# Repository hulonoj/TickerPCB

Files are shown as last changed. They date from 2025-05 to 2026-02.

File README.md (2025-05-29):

# ESP32 14-Segment Ticker Board

A custom-built ESP32-based project using 14-segment hex displays to show real-time data like a clock, stock prices, temperature, and a chess timer.
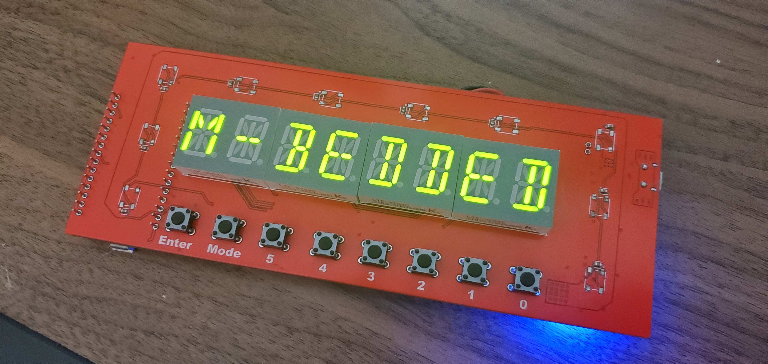
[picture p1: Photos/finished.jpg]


## What It Does
- Pulls real-time data via Wi-Fi
- Displays info on 8 14-segment displays
- Controlled with 7 physical buttons
- Runs on battery with power management

## Current Modes
- Temperature from 2 i2c sensors
- Real time clock accurate to ~1 second
- Stock Price for any ticker symbol you input
- Chess clock with 5 differet base times and increment

## Photos
Finished Board!

Shows live temperature readings in [temperature testing video](Photos/TempTesting.mp4) and accurate clock in [clock testing video](Photos/ClockTesting.mp4)

Temperature Readings
Clock Time

Schematic and Layout

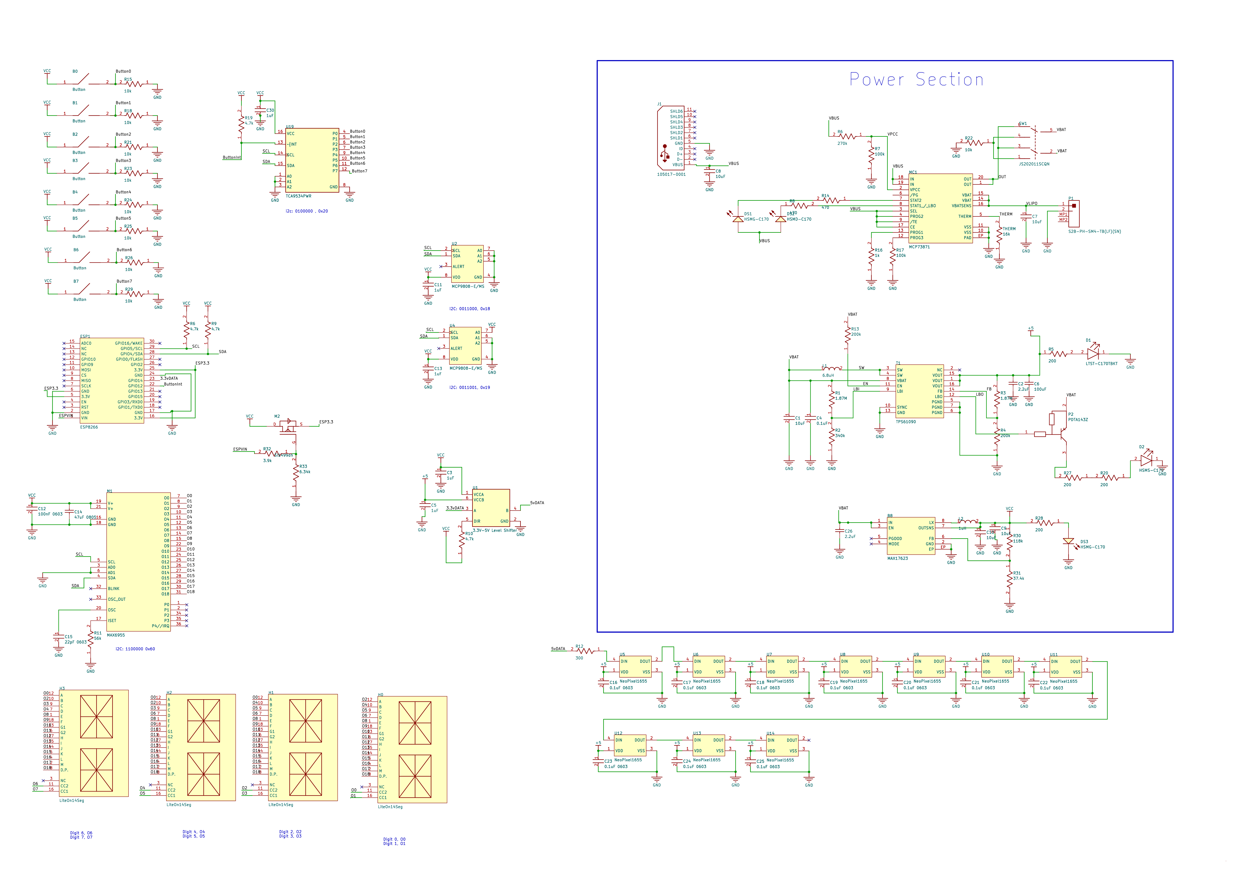
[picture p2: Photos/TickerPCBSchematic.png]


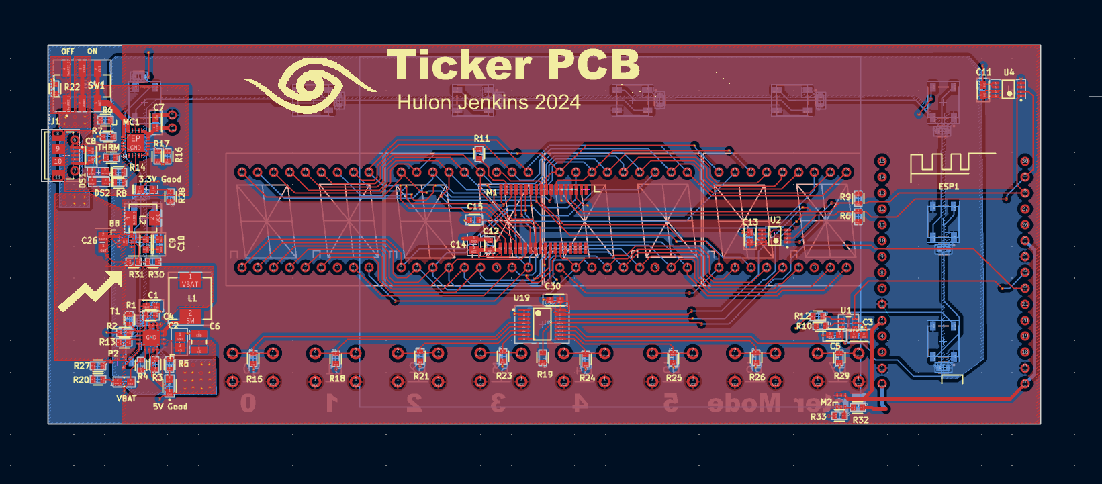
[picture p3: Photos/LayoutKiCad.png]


## Code Overview
Firmware is written in C++ and manages:
- I2C communication with display drivers
- GPIO input from buttons
- Wi-Fi data fetching
- State switching between display modes

Buttons presses trigger interrupts which are then handled and change state machines to change or move within modes.

## 📚 Notes
I designed and built this project as a personal challenge to deepen my embedded systems skills. The board and code were developed from scratch, and photos illustrate the final product.

## 📝 License
MIT

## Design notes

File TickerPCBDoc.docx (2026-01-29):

Design Considerations

Current from battery and to 3.3 and 5V rails (but didn’t calculate if BMS could handle 3.7V current which would be boosted to 5V).

Made the board 2 layers for cost reasons, even though 4 layers would be significantly better.

Issues

1. When soldering on the NeoPixel LEDS and powering up the board, the entire board shut down. This happened every time the LEDs were soldered on. I removed the LEDs and the resistor in series with the data line. My hypothesis is that the LEDs drew too much current (not for the 3.7v to 5V boost converter) but from the BMS since more current would be flowing at 3.7v compared to 5V. I didn’t get the LEDs to work on this design. From the datasheet “The ideal diode between VBAT and OUT is designed to drive a maximum current up to 2A. The built-in thermal shutdown protection may turn the MCP73871 device off with high current”

I designed a PCB using an MCP73871 to manage a 3.7 V Li-ion battery and power my system. The MCP73871’s SYS output feeds a boost converter that steps the voltage up to 5 V for NeoPixel LEDs. On paper this looked fine because the chip’s current rating seemed high enough.

In practice, as soon as I solder even a single NeoPixel onto the board and power it on, the entire system shuts down. What’s happening is that the NeoPixels and the boost converter create a large inrush current at startup. That transient load causes the MCP73871’s power-path circuitry on the SYS pin to brown out or current-limit, so it disconnects the output and everything turns off. The issue isn’t average current, it’s the startup surge and the fact that SYS is not meant to supply large, fast, pulsed loads through a boost converter.

The fix is to power the boost converter directly from the battery instead of the SYS pin and to add adequate bulk capacitance. That way the battery handles the current spikes, the MCP73871 only manages charging and light system loads, and the system no longer collapses when the LEDs are connected.

2. When placing the battery onto the board, I noticed that the battery positive and negative terminals were inverted compared to what the online version said. The battery connector mounts in a certain way based on the polarity and can only be plugged in one way. Since the battery terminals were reversed, I cut and stripped the wires, and resoldered them on and plugged the battery in so it worked. I also ordered a new higher capacity battery which definitely had the right connector order for a more permanent solution.

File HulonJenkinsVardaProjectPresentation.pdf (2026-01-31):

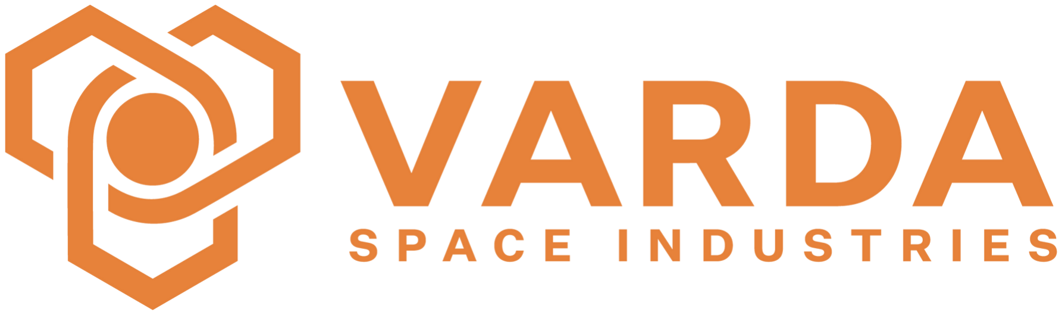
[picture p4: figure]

# Project Presentation

Hulon Jenkins

## Agenda

- About Me
- University/Microsoft Projects
- Personal Project Overview
- Planning
- Architecture
- Parts Selection
- Schematic & Layout
- Roadblocks and Debugging
- Software/Firmware Quick Look
- Results and Lessons Learned
- How I Engineer
- Questions
- Demo (if time)

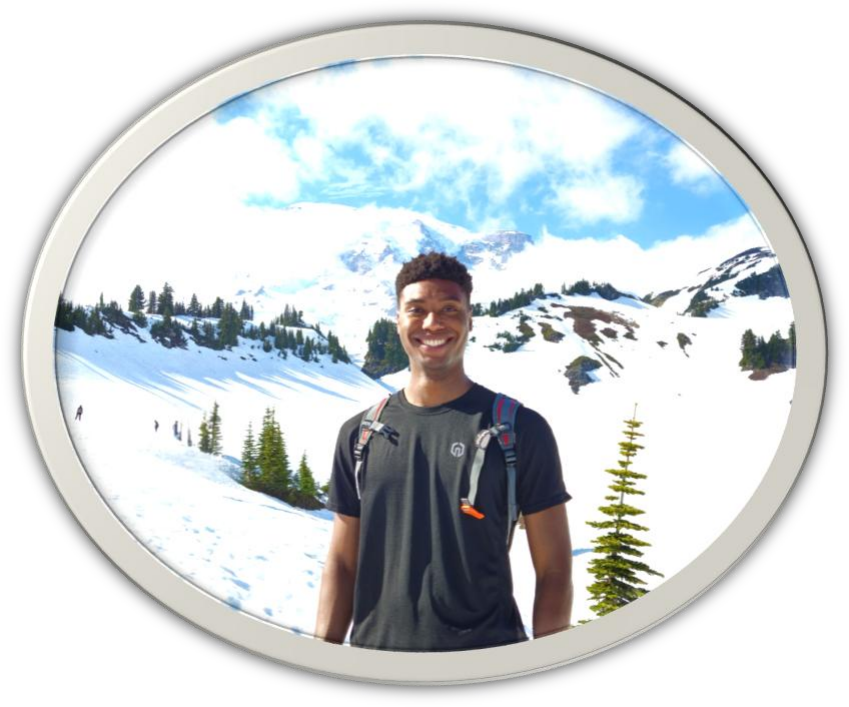
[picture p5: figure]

## About Me – Hulon Jenkins

Focus
- Embedded hardware and electronics design and bring up Education
- BSE Computer Engineering from University of Michigan
- Currently pursuing MS Electrical Engineering part time through University of Colorado Boulder
Experience
- Embedded Hardware Team Lead and member on Michigan Mars Rover Team
- Currently work at Microsoft (C++ Compiler)
Interests
- Spaceflight, Table Tennis, 3d Printing

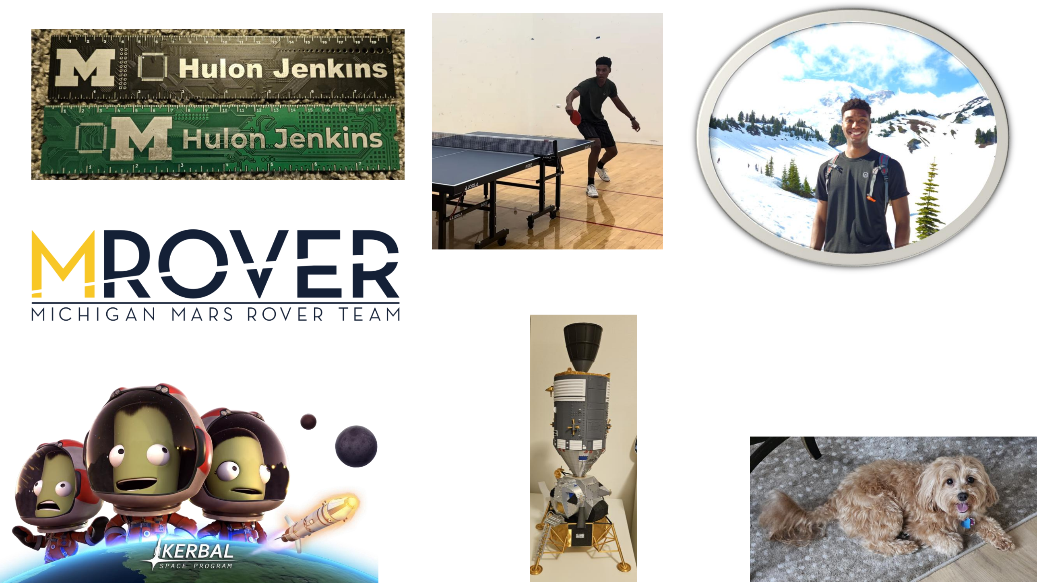
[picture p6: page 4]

## University - MROVER

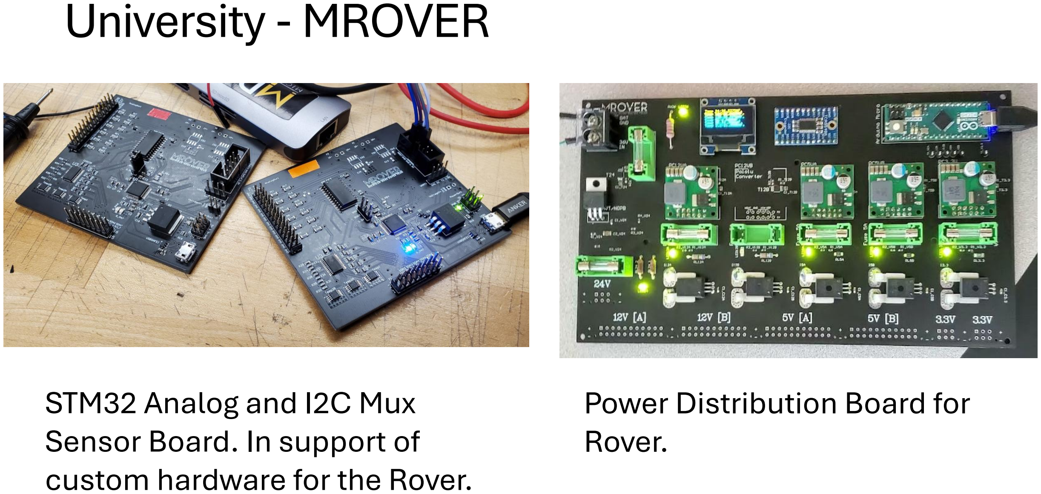
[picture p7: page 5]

Power Distribution Board for Rover.

STM32 Analog and I2C Mux
Sensor Board. In support of custom hardware for the Rover.

## University - Classes

- A Drop-In Wire Replacement using Fiber Optics
- Is Protocol Agnostic
- Replicates signals on wires. Which can be interpreted as I2C, SPI, UART, GPIO, etc.

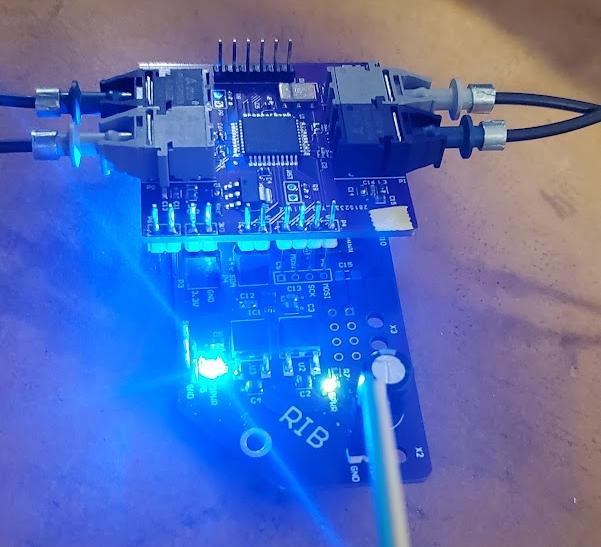
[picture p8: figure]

- We used it to replicate I2C over a length of 5 meters

## Microsoft

- Pattern Matching Software Security Tool Team
- Implemented patterns and logic to statically match a secret and validate if that secret was still live
- C++ Compiler Team
- Worked on a large optimization with tail calling which is used in upcoming Python Interpreter!

## Personal Project Overview

- ESP8266 based 14-segment display board
- Battery powered
- 8 Button input
- Wifi Connected

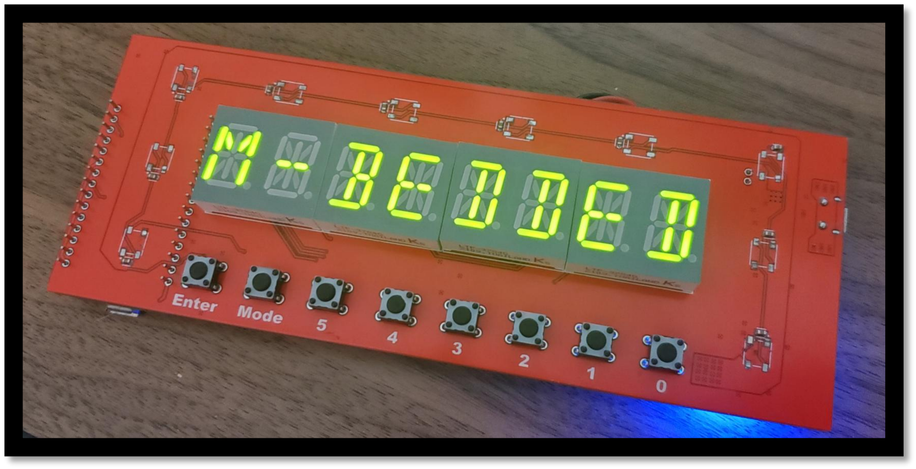
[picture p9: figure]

## Project Requirements & Initial Planning

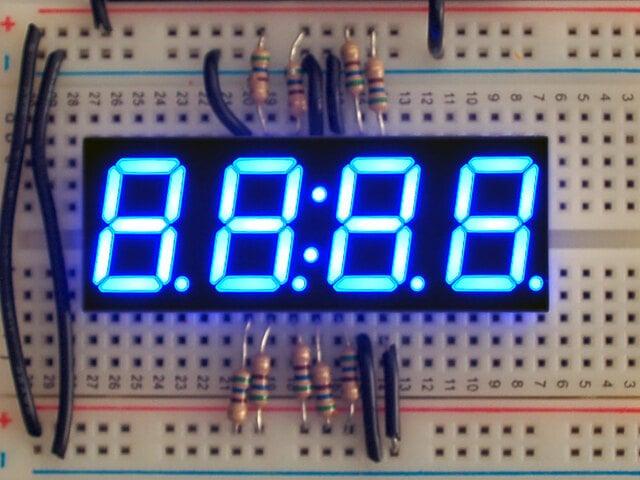
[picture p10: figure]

- Main goal, be able to display real time stock data on
hex displays
- Must be internet connected

## Project Requirements & Initial Planning

- 14-segment allows for alphanumeric characters.
- Can display temperature data as well
- Mobile, so battery powered
- All interfacing will be through the 14-segments displays
- Would need buttons for inputs
- Have LEDs that can change color/brightness as well
- Main goal, be able to display real time stock data on hex displays
- Must be internet connected

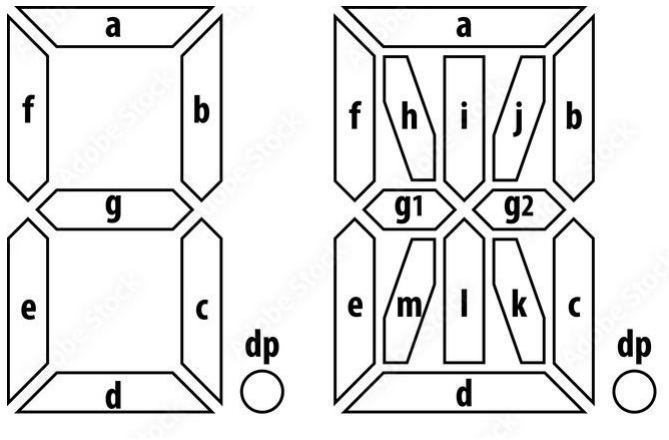
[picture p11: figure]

## Design and Architecture (1/2)

Connectivity and Main Controller
- 3.3V Esp8266 for Wi-Fi connectivity

Power
- 3.7V rechargeable LiPo battery

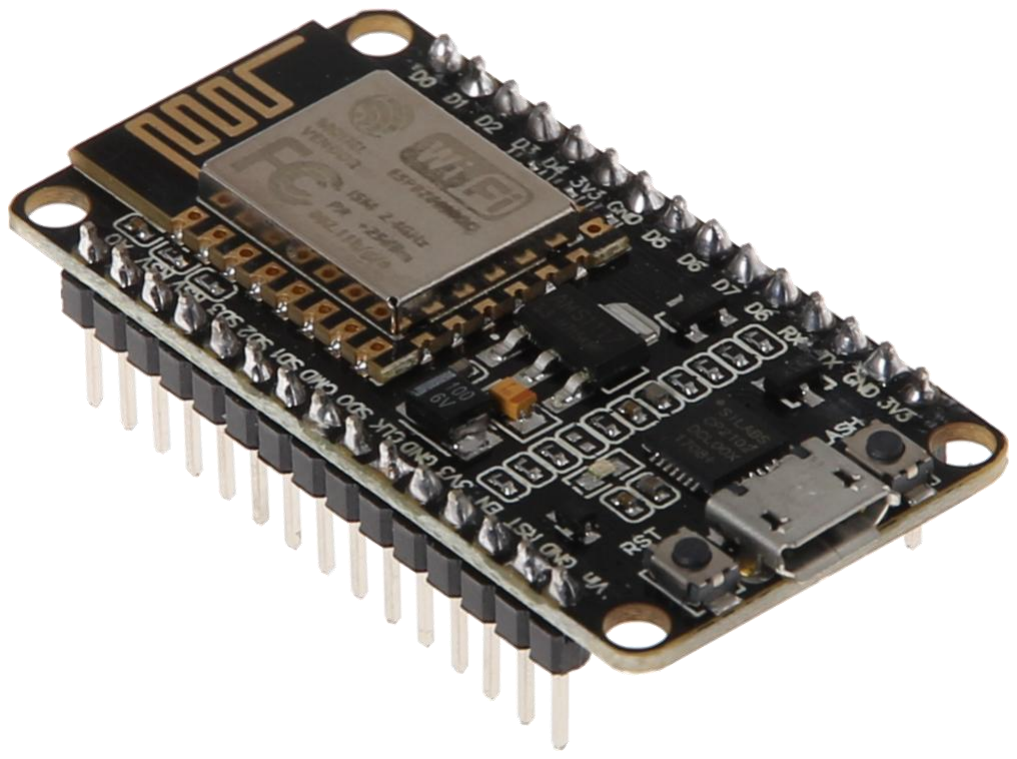
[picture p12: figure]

- Passthrough charging IC (Can charge battery and use simultaneously)
- Buck Converter for 3.7V → 3.3V
- Boost Converter for 3.7V → 5V

## Design and Architecture (2/2)

Outputs
- 3.3V 14-Segment Displays
- 5V individually addressable NeoPixel LEDs Inputs
- Multiple tactile switches
Logic
- Logic level shifter for 3.3V Esp8266 logic to 5V for NeoPixels
- 14-Segment Control IC for simplicity
- 3.3V Temperature sensors

## Block Diagram

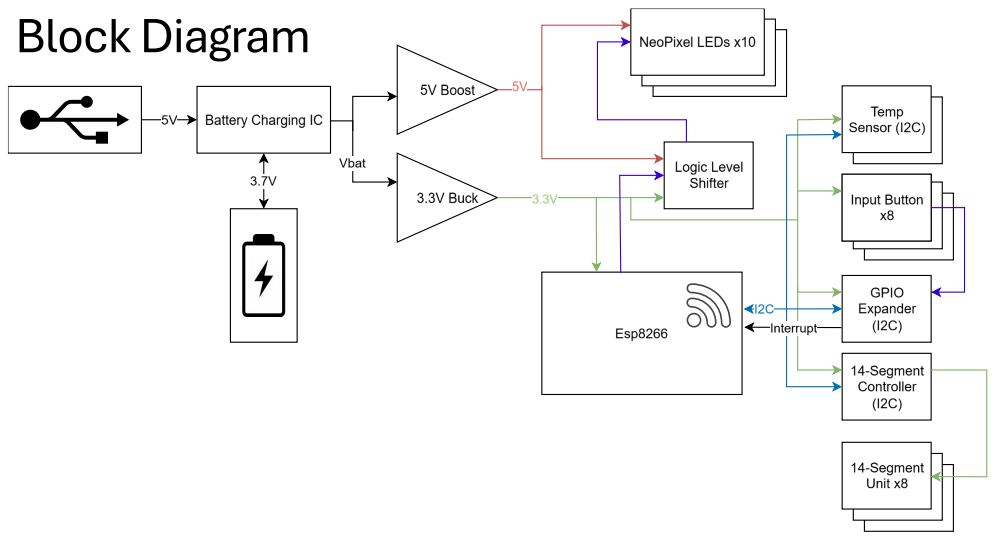
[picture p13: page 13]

## Implementation Details (1/2)

Functionality | IC Selected | Why
Battery Charger | MCP73871 | CC/CV, Load Sharing + Battery Charging, Indication and Safety (temp, short protection)
14-Segment Controller | MAX6955 | I2C, Can control 8 14-segments, can PWM LEDs to reduce current draw
Buck Converter | MAX17623 | Up to 1A @ 3.3V
Boost Converter | TPS61090 | Up to 500mA @ 5V
GPIO Expander | TCA9534PWR | I2C, 8 inputs, has interrupt pin
Logic Level Shifter | SN74LVC1T45-Q1 | Converters 3.3V logic to 5V with 3.9ns delay
Temperature Sensors | MCP9808-E/MS | I2C, address pins, 0.0625C accuracy
NeoPixels | NeoPixel 1655 | Multicolor, individually addressable

## Implementation Details (2/2)

Functionality | Details | Why
MCU | ESP8266 Dev Board | I had the dev board in hand already, was going to have enough external circuitry to test
USB | Micro USB connector | The Esp8266 already has a Micro USB. I’d prefer USB Type C, but would prefer consistency
Buttons | Tactile Switches | Cheap easy to use with pull-down resistor
Battery | 3000 mAh 3.7V Battery | Expected ~40mA*8 + ~30mA*10 + ~100mA = 720mA of current, so would last a ~4 hours on battery power at full brightness

## Block Diagram

## Initial Trials

- Breadboarded 14-segment displays and Esp8266 connectivity and control

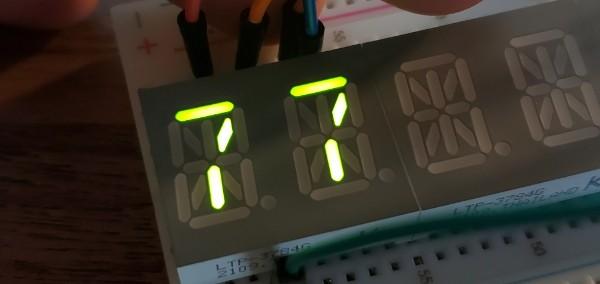
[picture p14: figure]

## Schematic

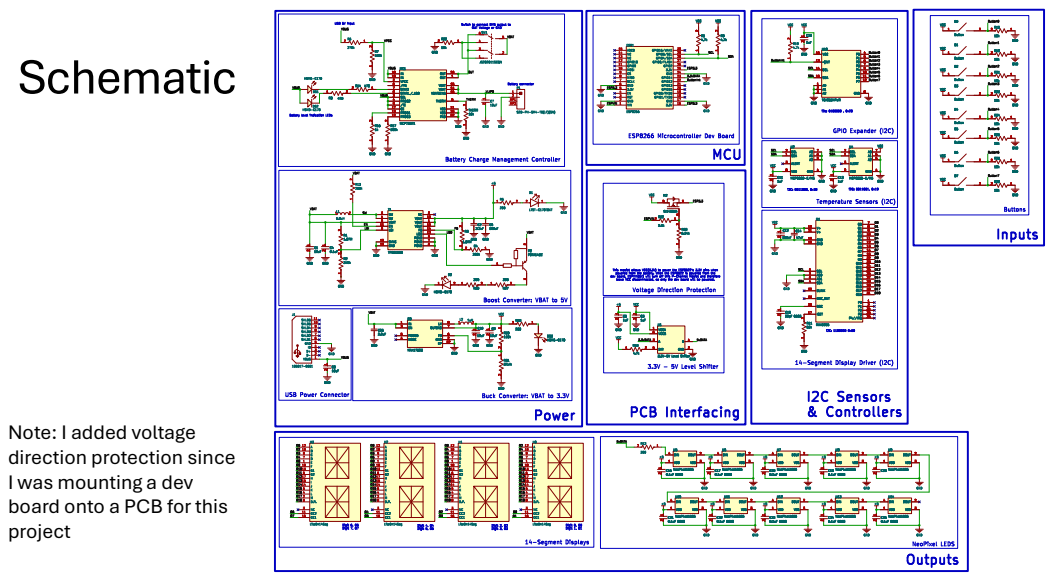
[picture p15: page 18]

Note: I added voltage
direction protection since
I was mounting a dev
board onto a PCB for this
project

## PCB layout (2 layer)

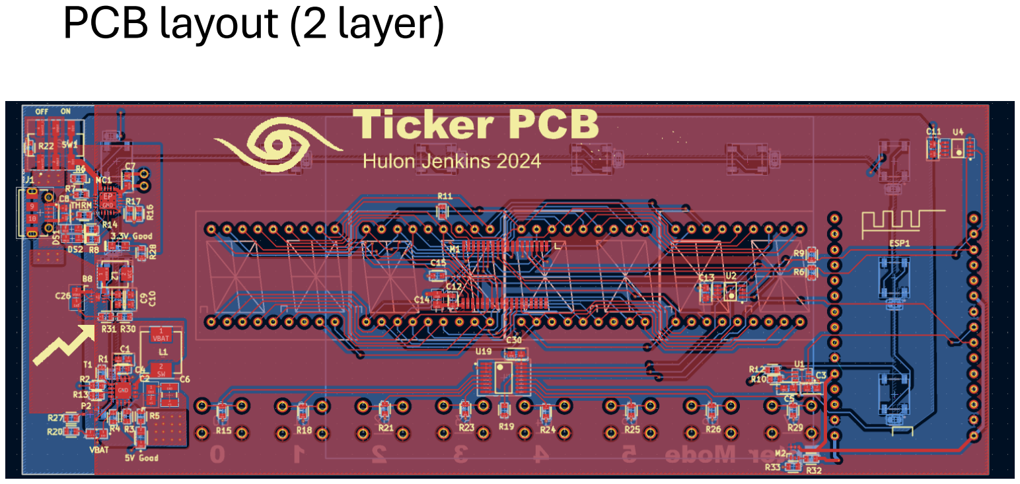
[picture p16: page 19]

## Integration and Build Process

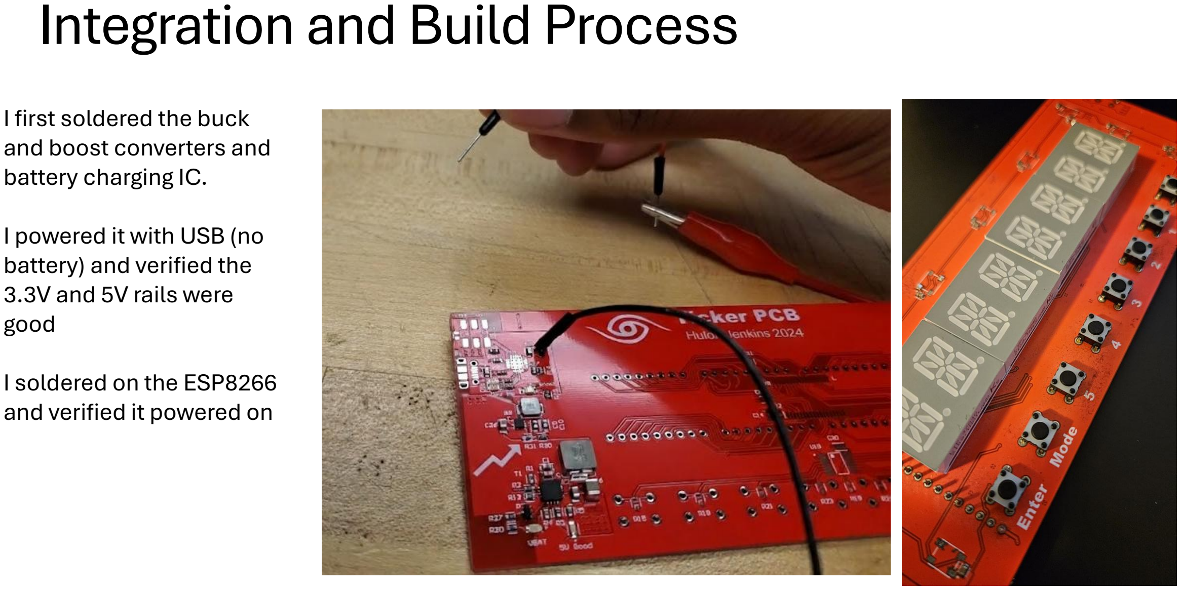
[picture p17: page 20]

I first soldered the buck
and boost converters and
battery charging IC.

I powered it with USB (no
battery) and verified the
3.3V and 5V rails were
good

I soldered on the ESP8266
and verified it powered on

## Roadblocks and Debugging

- When I soldered on NeoPixel LEDs, all power good LEDs went off and everything on board instantly shut down

## Investigation Steps

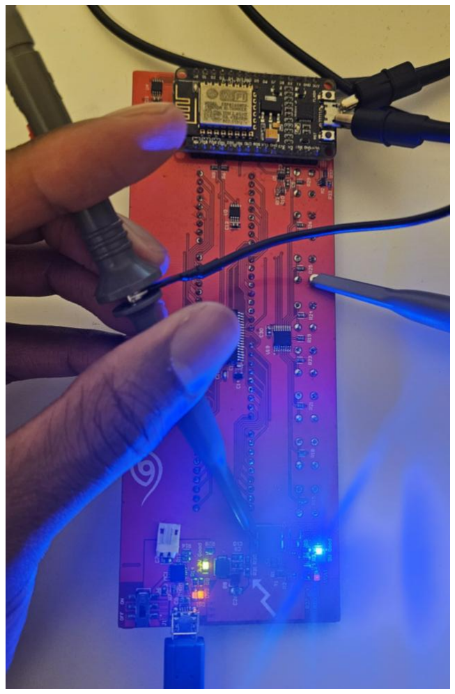
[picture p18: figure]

- Desoldered the NeoPixels and the board worked again.
- Verified footprint and pinout was correct.
- Verified once more 5V was good.
- Tried with other Neopixels but saw the same behavior.

## Investigation Steps

- I started attaching loads to the 5V rail and checking the voltage; it was fine.
- However, I noticed when I used a 47.5Ohm power resistor load, the 3.3V LED no longer lit up…
- Time to scope…

## Debugging

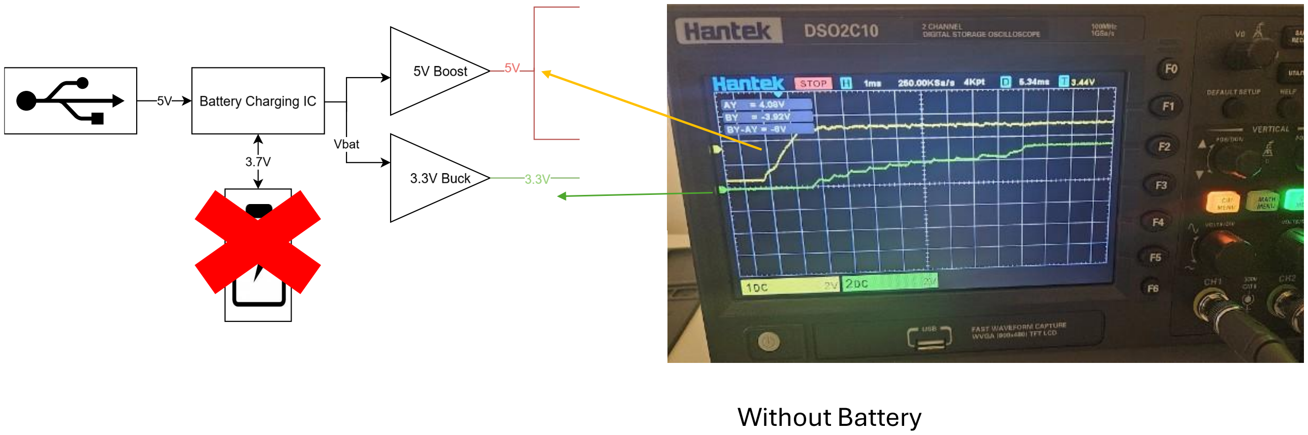
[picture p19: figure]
Without Battery

3.3V takes 9ms to ramp up!

## Debugging

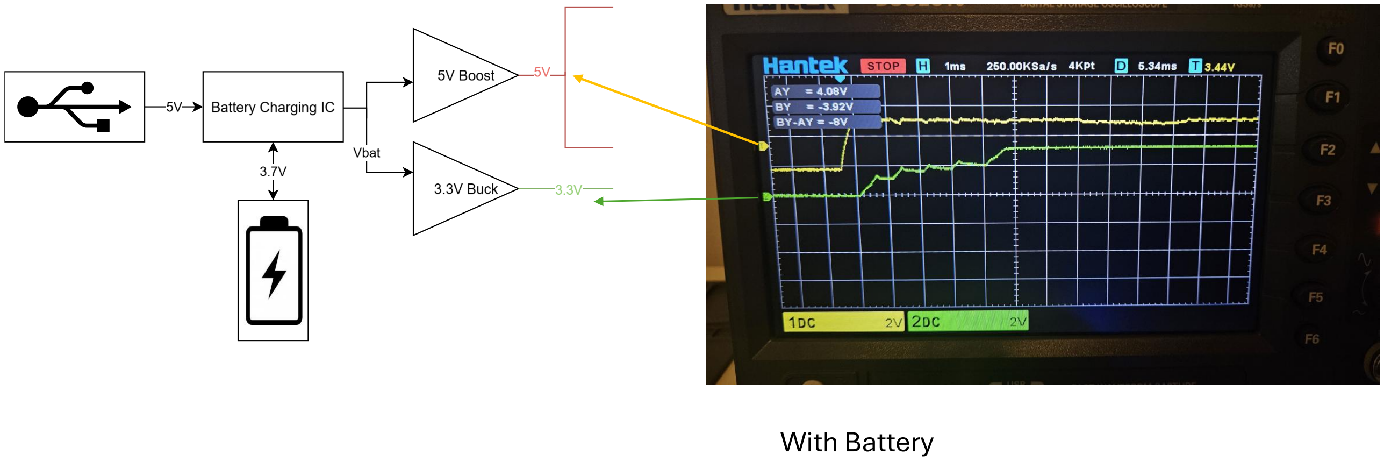
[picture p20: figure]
With Battery

3.3V takes 5ms to ramp up! Much faster!

## Debugging

- I wanted to recreate the NeoPixel fault condition, which was with no battery and a load on 5V

## Debugging

3.3V rail never gets to 3.3V!

## Debugging

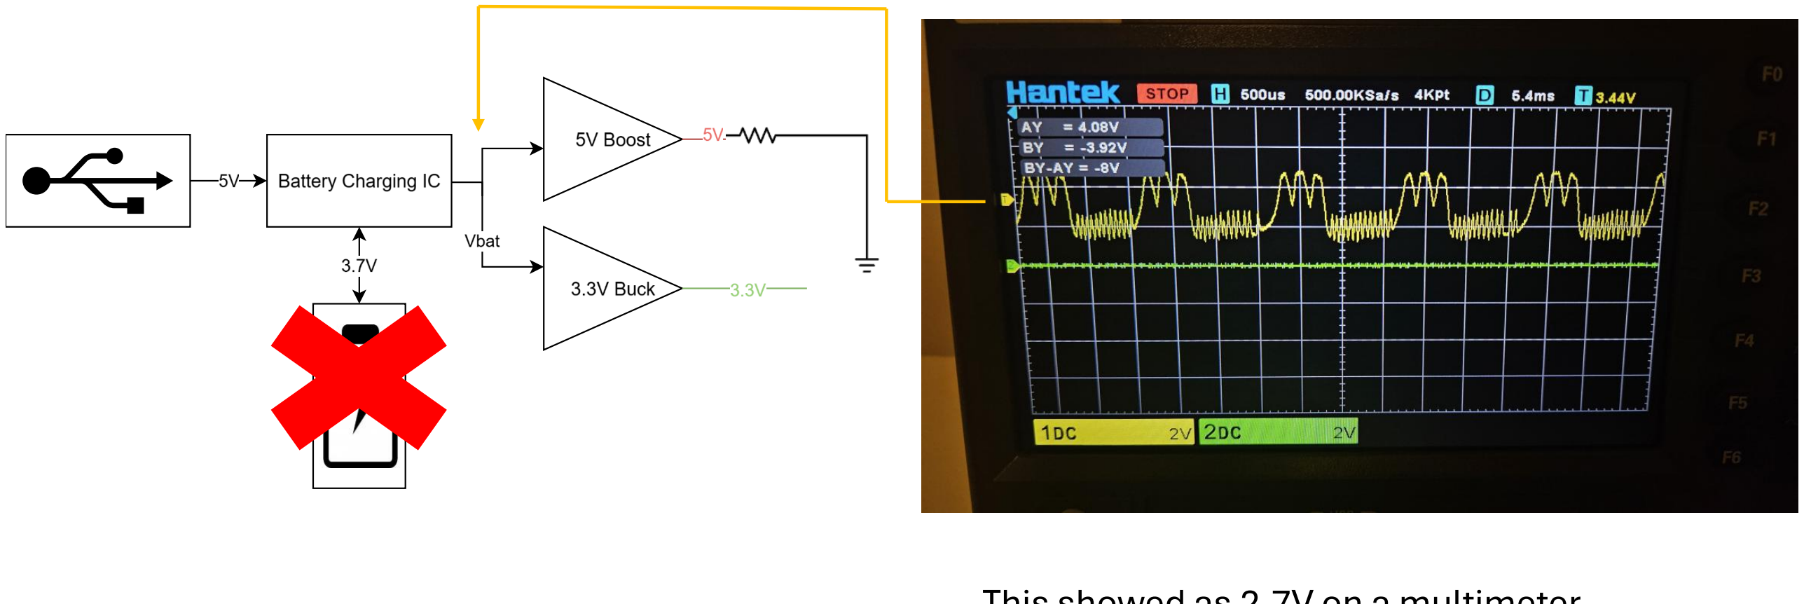
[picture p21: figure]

This showed as 2.7V on a multimeter.

Buck converter cannot reduce 2.7V to 3.3V

## Debugging

I looked at the datasheet which says that the chip should be able to work with or without a battery

However, with not battery, I was seeing the OUT voltage drop with a load

## Conclusion

With OUT voltage too low, the buck converter cannot operate any longer, but the boost converter still boosts this lower voltage up to 5V!

Hypothesis:
With a larger load (more current), OUT voltage can drop even more. If it falls below 1.8V, the boost converter can no longer function, shutting everything down.

## Workaround

- The ESP8266 and 3.3V worked without the NeoPixels, so I made the tradeoff of leaving them off and continuing with other parts of the project

Note:
I did this investigation after I removed the NeoPixels and haven’t resoldered and tested again.

## Firmware (1/3)

- Made drivers to handle I2C register reads/writes for GPIO Expander, 14-Segment Controller, Temperature Sensors
- Set the GPIO expander interrupt pin to trigger a read of the button states
- Then made functions to abstract away the lowest level functions

## Firmware (2/3)

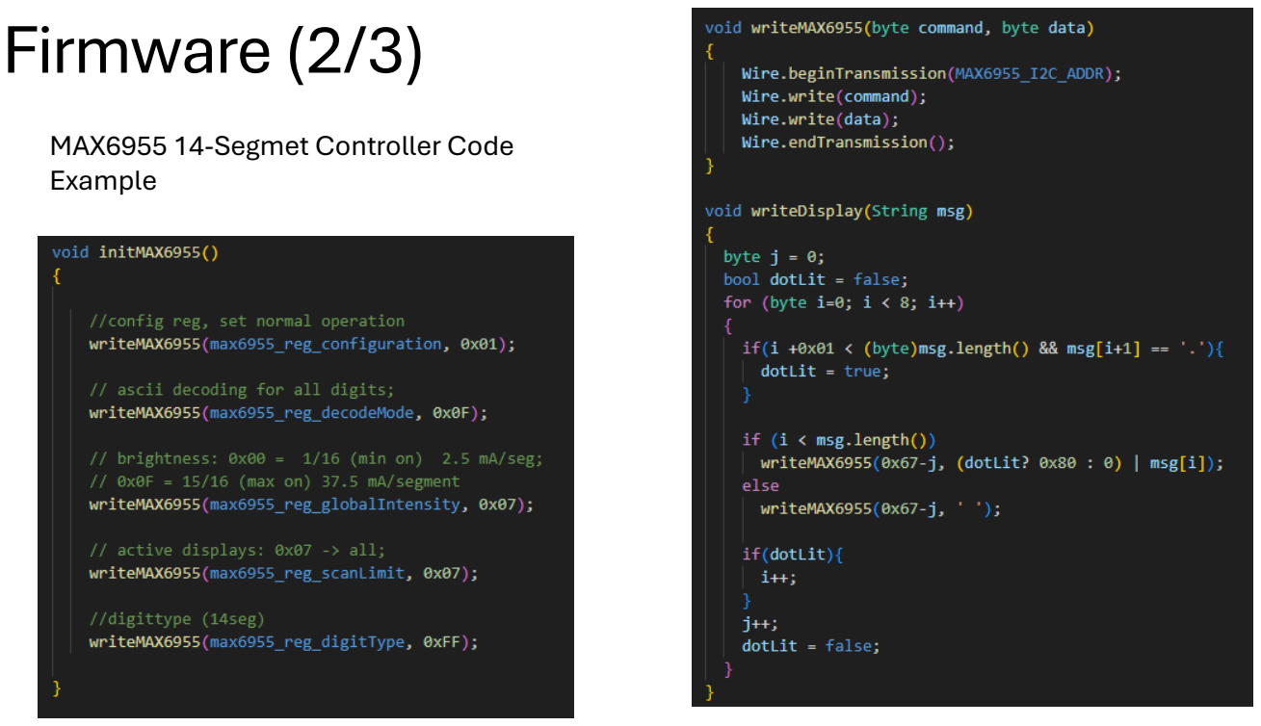
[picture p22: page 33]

MAX6955 14-Segmet Controller Code Example

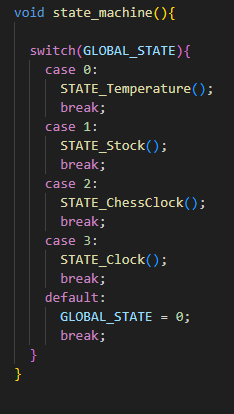
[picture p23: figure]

## Software (3/3)

- Have state machine for each mode
- Each mode is an entire additional and unique state machine that handles inputs from ‘Enter’ or Buttons #0-#5, makes API calls, updates the display, and whatever else it needs to do

## Results and Validation

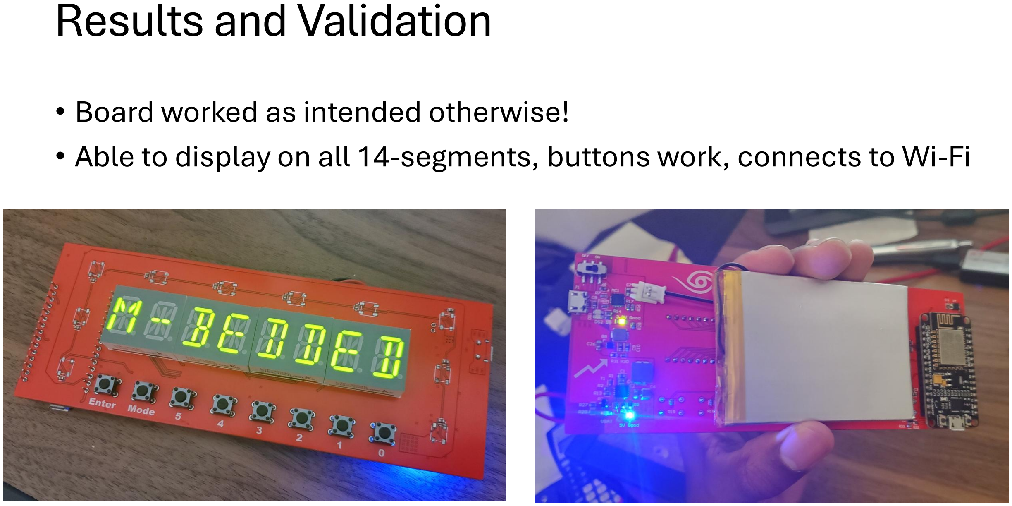
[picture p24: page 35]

- Board worked as intended otherwise!
- Able to display on all 14-segments, buttons work, connects to Wi-Fi

## Lessons Learned

- 4-layer board
- Don’t use a devboard
- Different Charging Chip
- Use buck-boost converter on 3.3V rail
- Power up 3.3V first, then use GPIO to enable 5V boost converter from microcontroller to prevent power sequencing issues

## My Engineering Approach

1. Define the ideal outcome
2. Define any requirements & limitations that go along with the ideal outcome
3. Research and tradeoffs
4. Identify any unknowns or risky aspects and test/prototype them
5. Redefine/Shift ideal outcome with data

6 . Make it! (and take notes)

## Working in teams

- I like to work on teams where everyone contributes and has a common goal
- I appreciate individual thinking followed by group discussion to work out the best solution
- I value teams who document their knowledge and iterate forward
- I value interfacing between teams (Hardware – Software – Mechanical)

## Questions

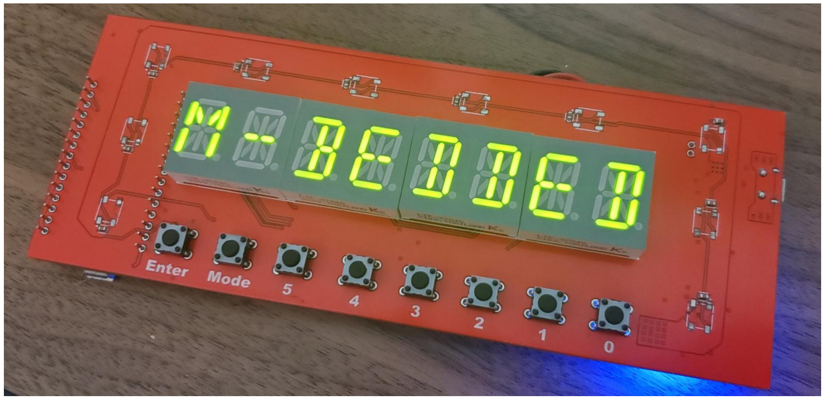
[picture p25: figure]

## Demo

## Extra – Load Sharing Breadboard Power Supply

(1/3)

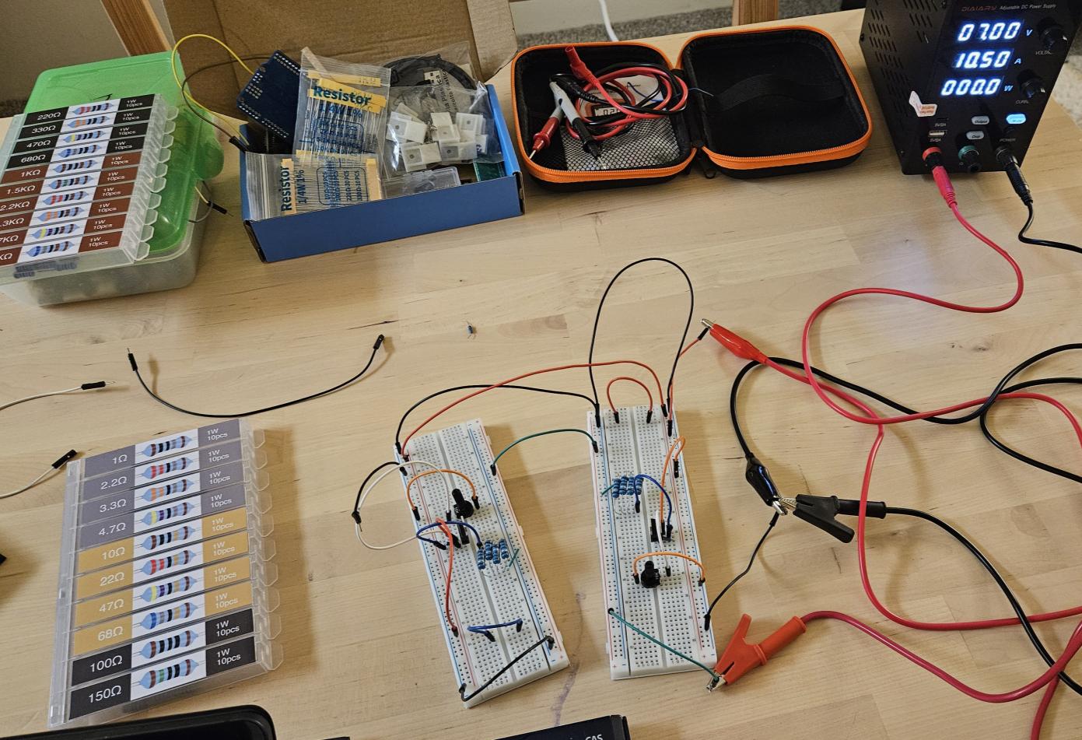
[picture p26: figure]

## Extra – Load Sharing Breadboard Power Supply

(2/3)

## Extra – Load Sharing Breadboard Power Supply

(3/3)

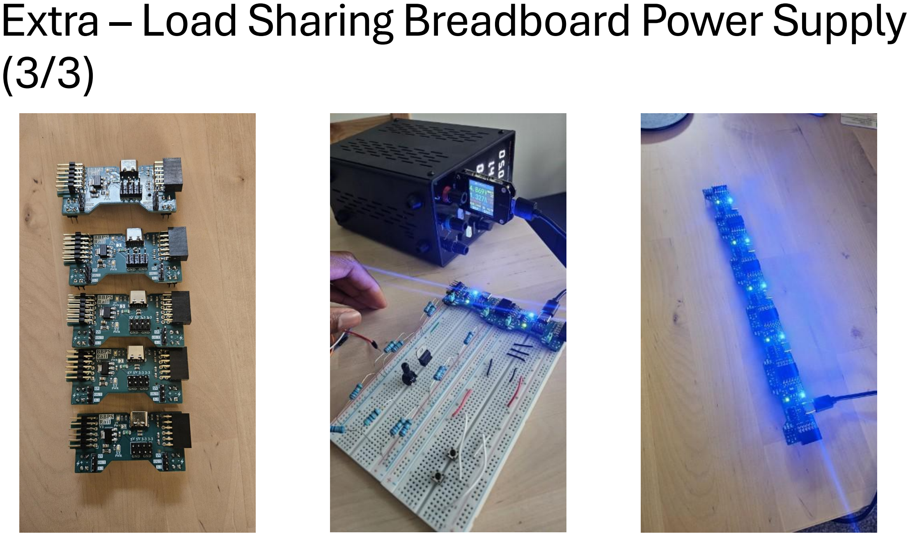
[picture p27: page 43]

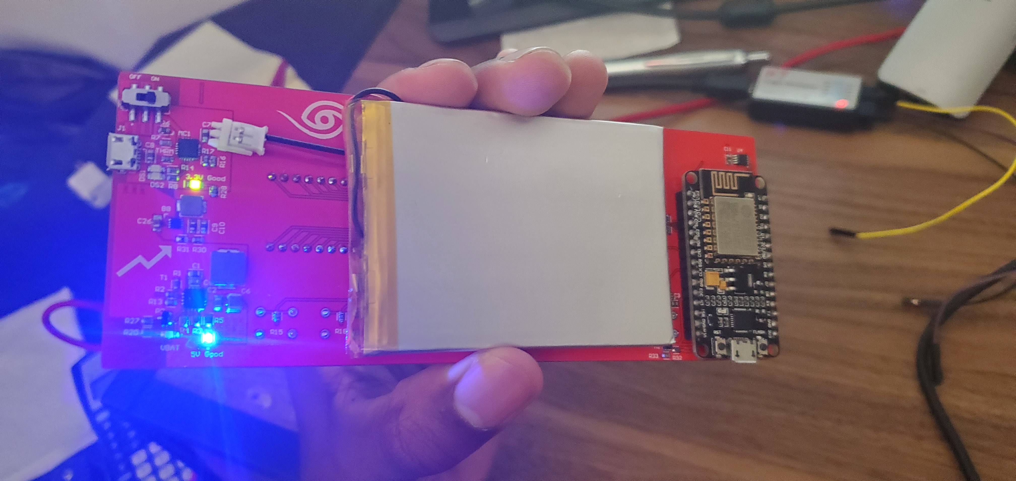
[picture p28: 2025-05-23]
Photos/BoardPoweredOn.jpg

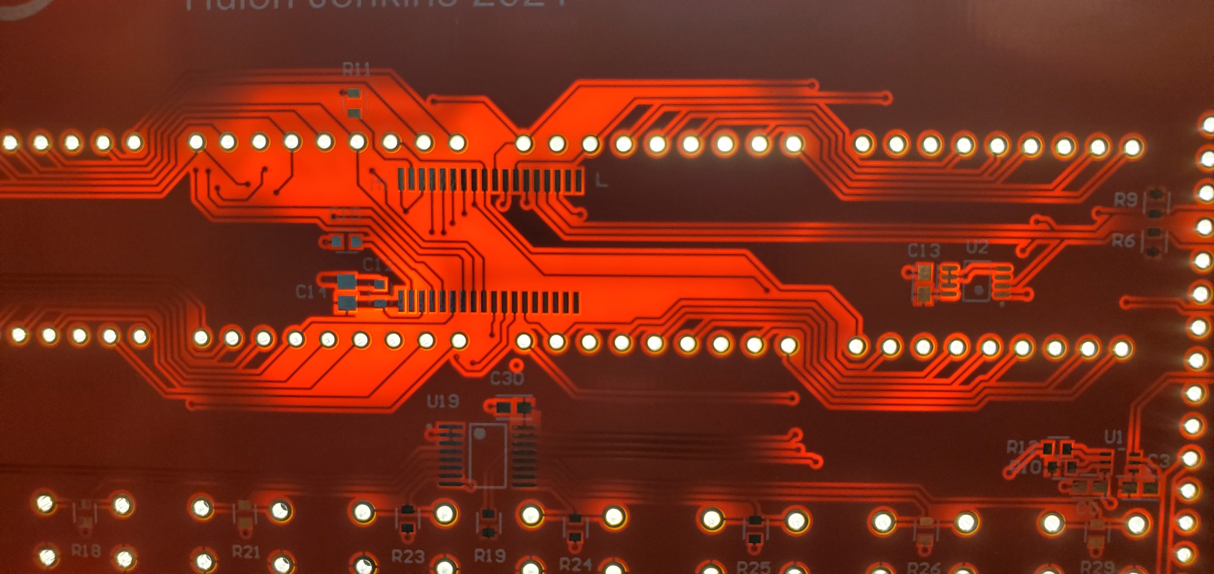
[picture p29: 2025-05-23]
Photos/barePCBSillouete.jpg

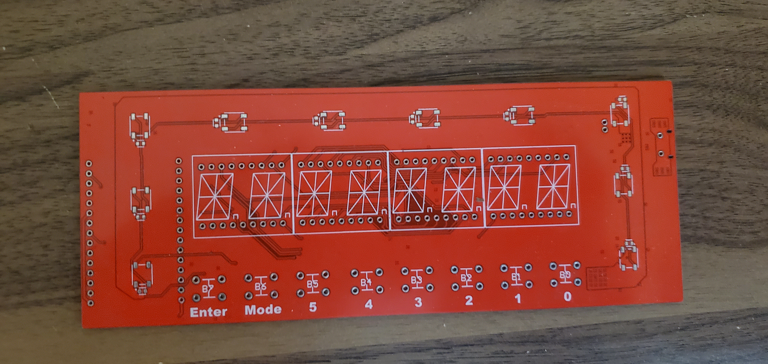
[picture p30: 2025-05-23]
Photos/BlankPCB.jpg

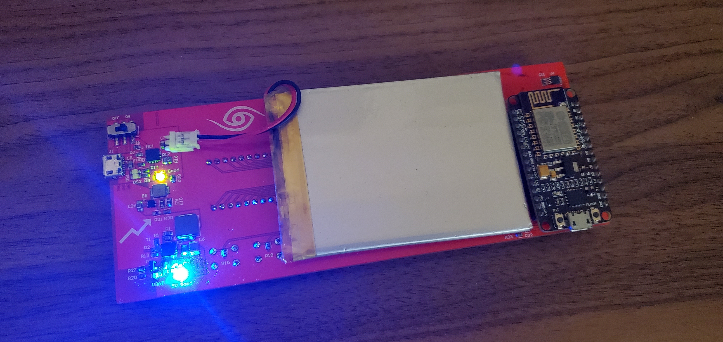
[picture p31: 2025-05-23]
Photos/backOfPCB.jpg

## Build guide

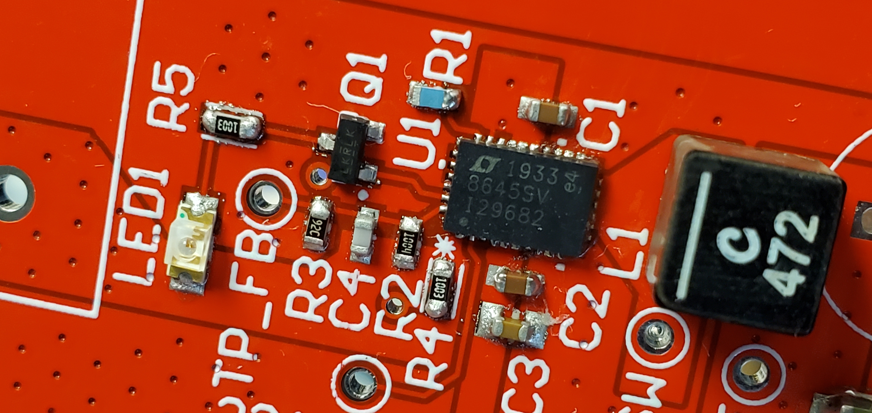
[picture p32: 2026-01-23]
Photos/PowerSectionAssembled.jpg

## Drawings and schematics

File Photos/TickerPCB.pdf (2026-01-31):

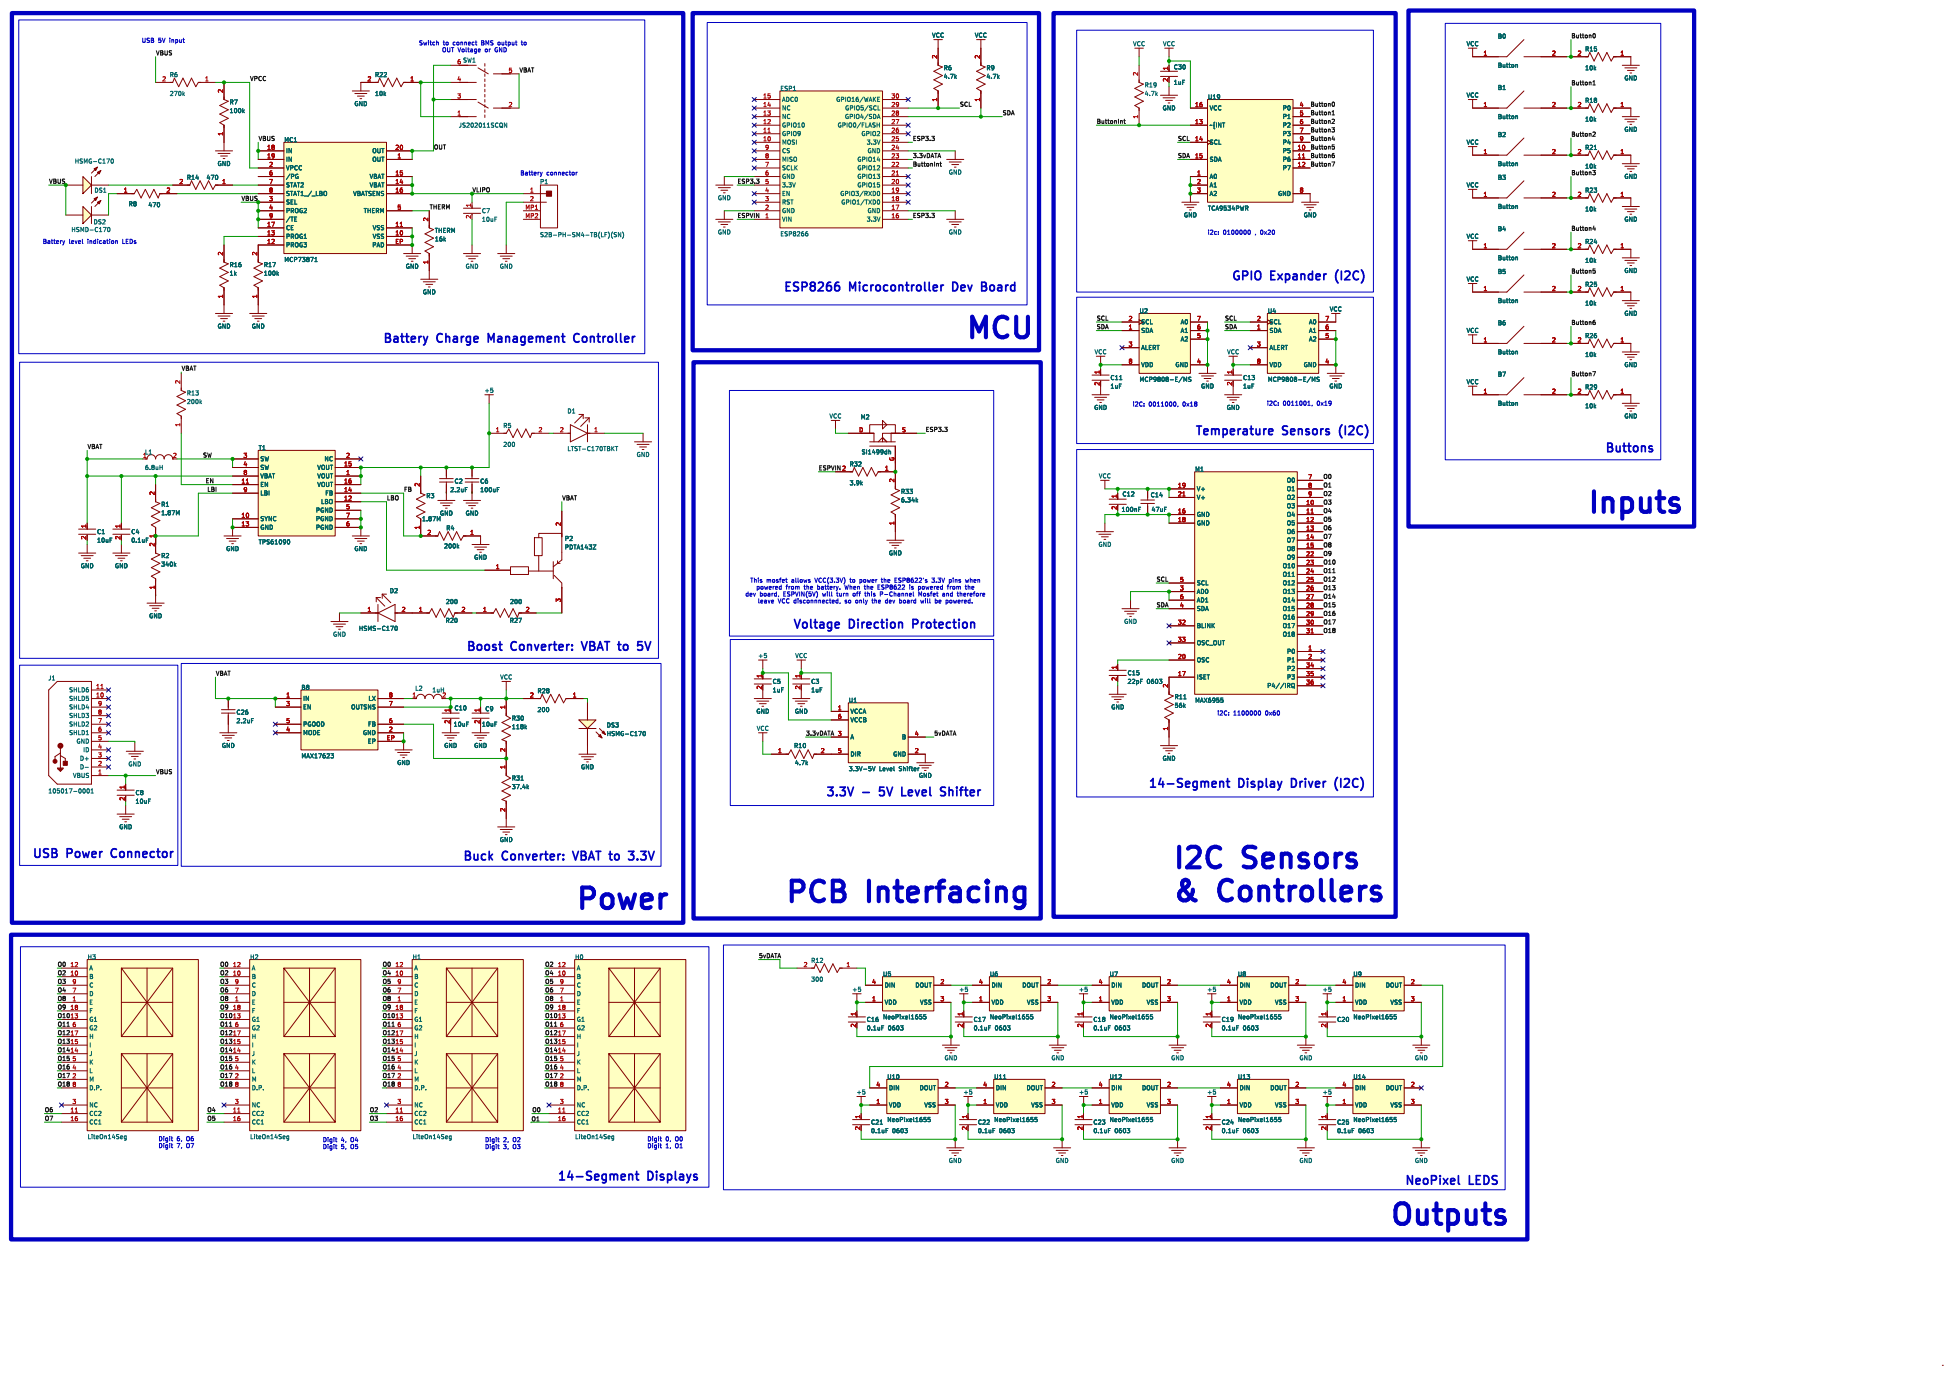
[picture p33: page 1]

Battery connector Boost Converter: VBAT to 5V

Battery Charge Management Controller

powered from the battery. When the ESP8622 is powered from the

1 2 U11 NeoPixel1655 DIN 4 VDD 1 DOUT 2 VSS 3 C22

Digit 0, O0 Digit 1, O1 Digit 2, O2 Digit 3, O3 USB Power Connector

Buck Converter: VBAT to 3.3V

1 2 U10 NeoPixel1655 DIN 4 VDD 1 DOUT 2 VSS 3 U5 NeoPixel1655 DIN 4 VDD 1 DOUT 2 VSS 3 C16

1 2 U6 NeoPixel1655 DIN 4 VDD 1 DOUT 2 VSS 3

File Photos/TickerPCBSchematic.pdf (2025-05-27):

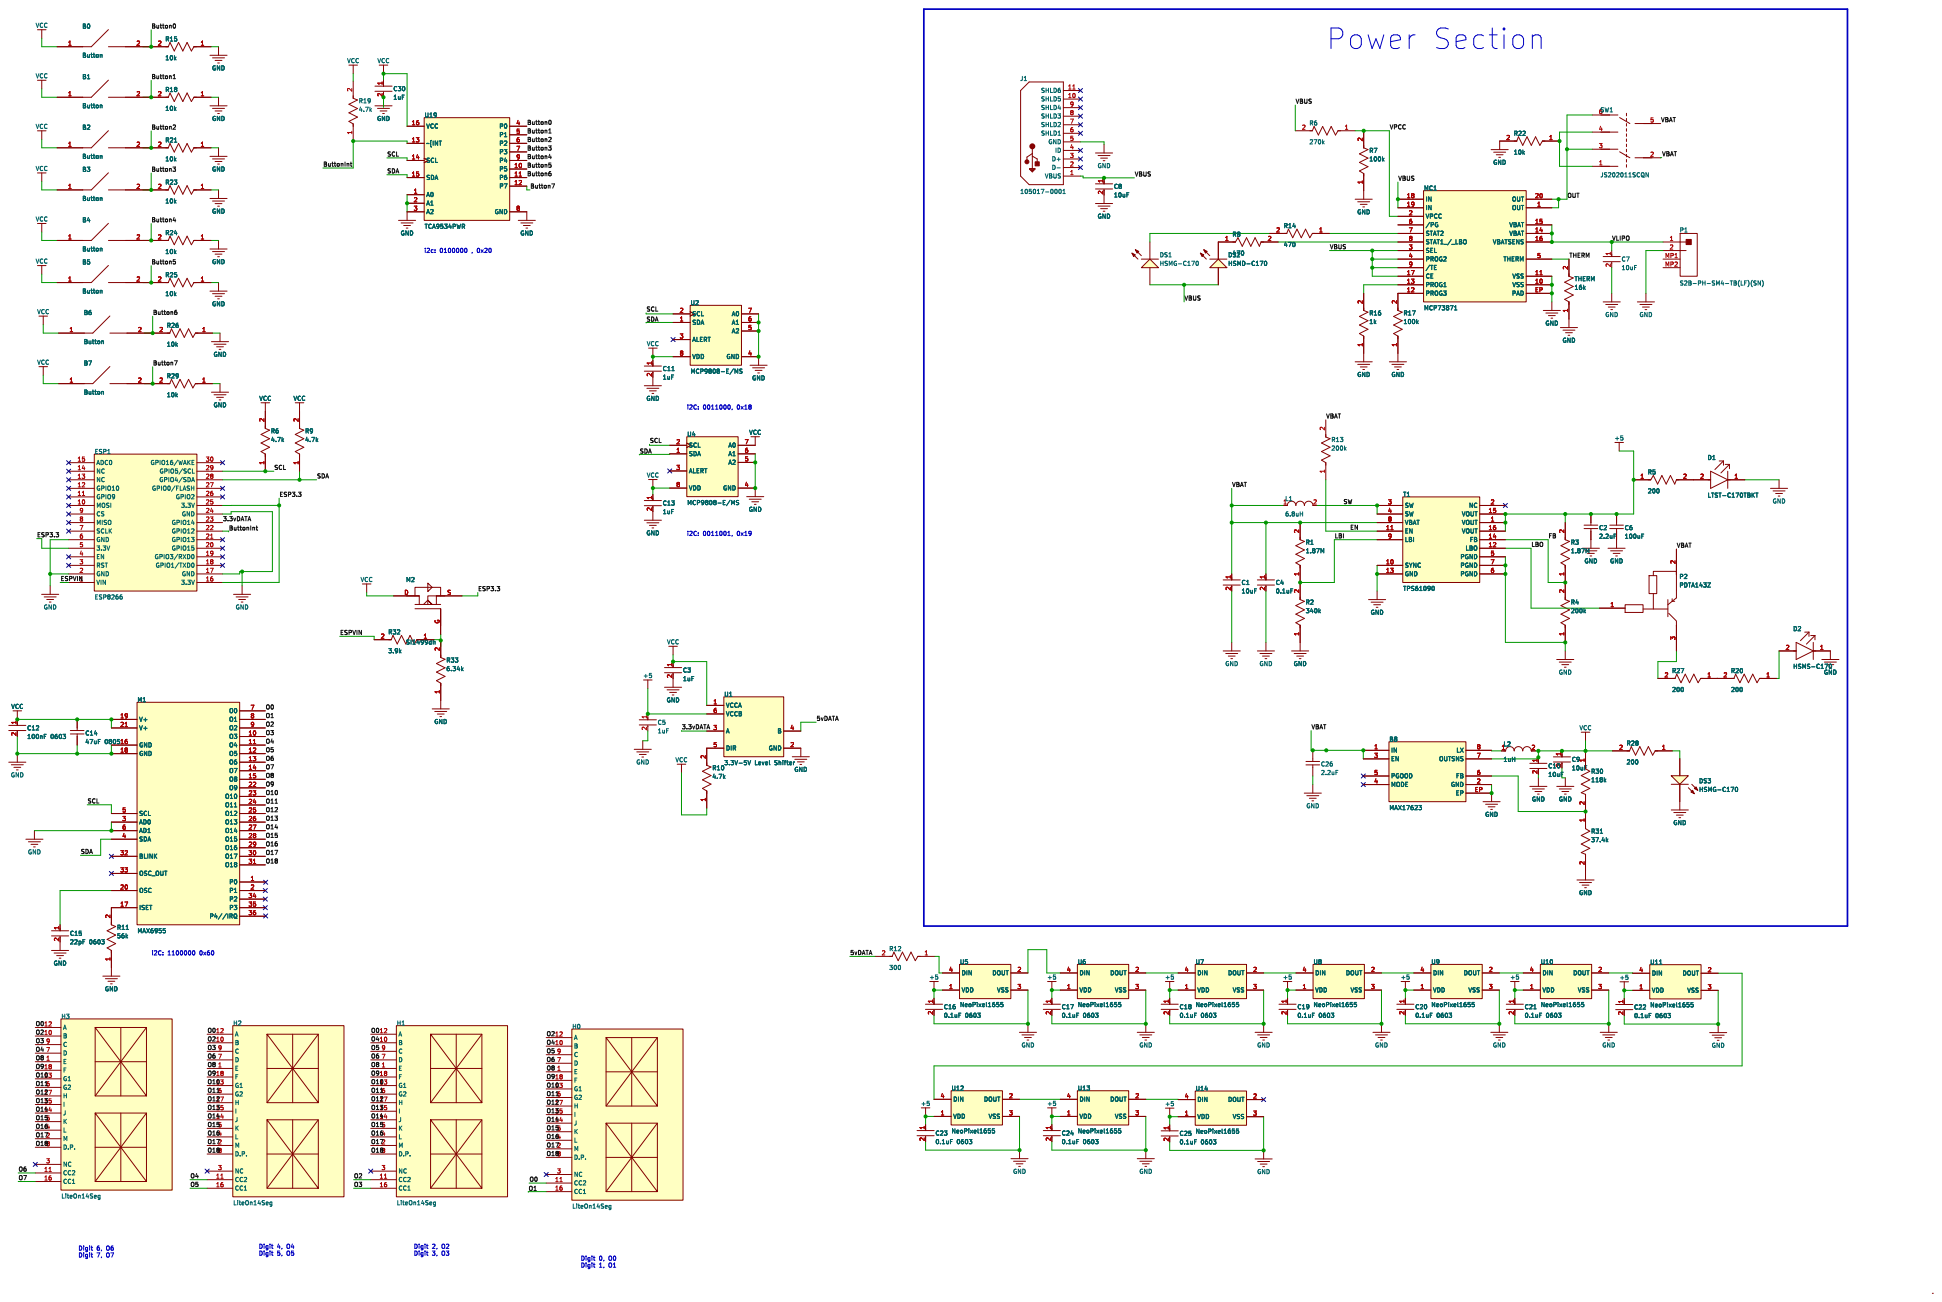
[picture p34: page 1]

2 1 U6 NeoPixel1655 DIN 4 VDD 1 DOUT 2 VSS 3 C17

1 2 U5 NeoPixel1655 DIN 4 VDD 1 DOUT 2 VSS 3 C19

1 2 U12 NeoPixel1655 DIN 4 VDD 1 DOUT 2 VSS 3 C25

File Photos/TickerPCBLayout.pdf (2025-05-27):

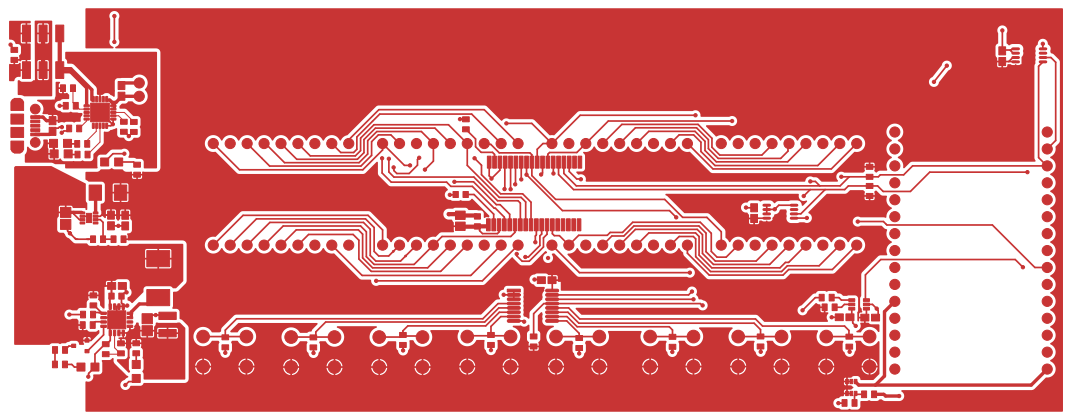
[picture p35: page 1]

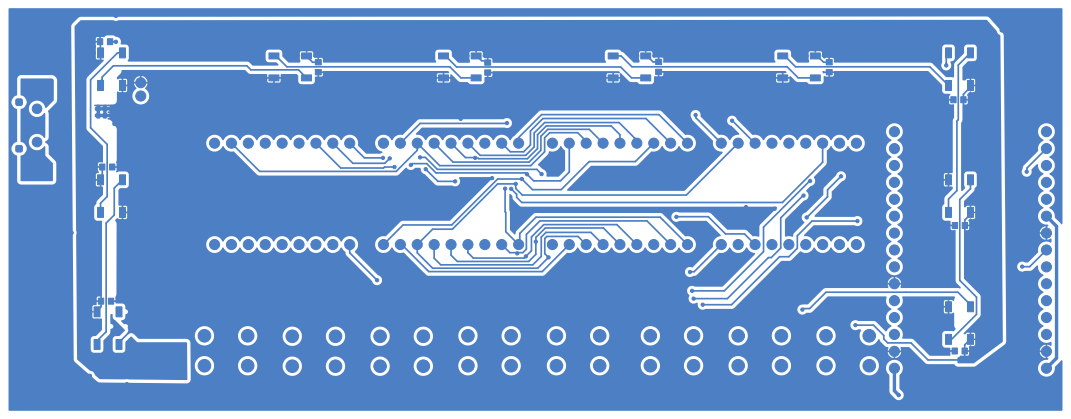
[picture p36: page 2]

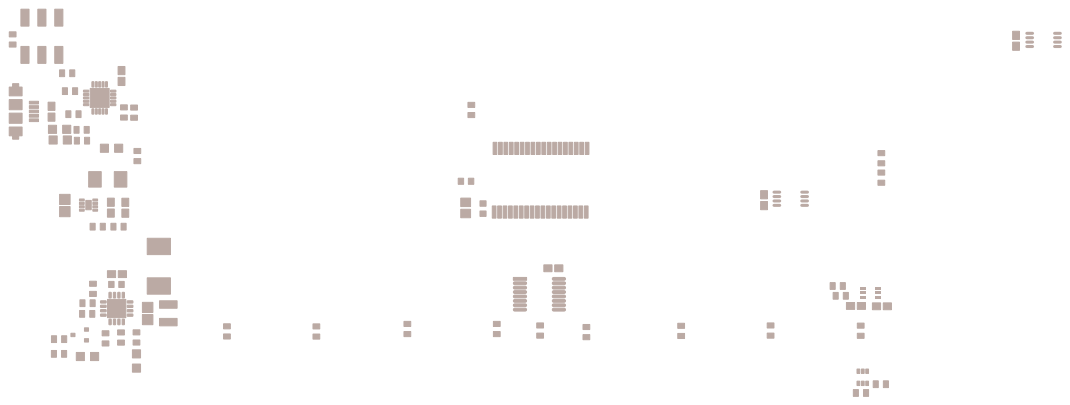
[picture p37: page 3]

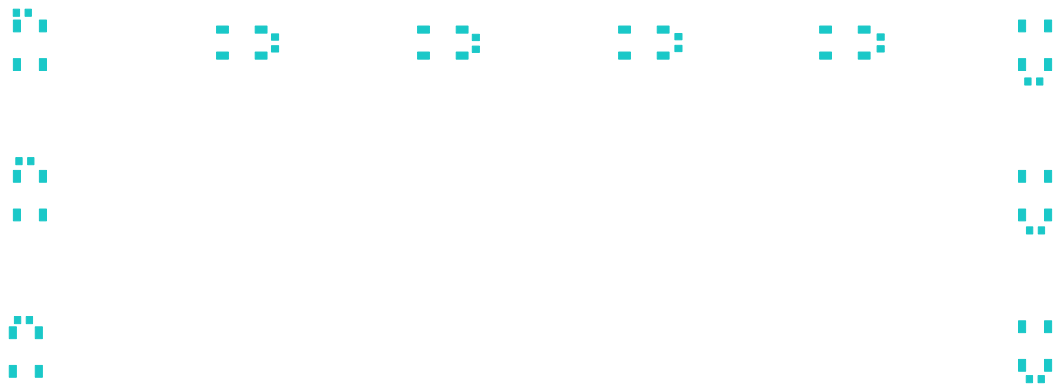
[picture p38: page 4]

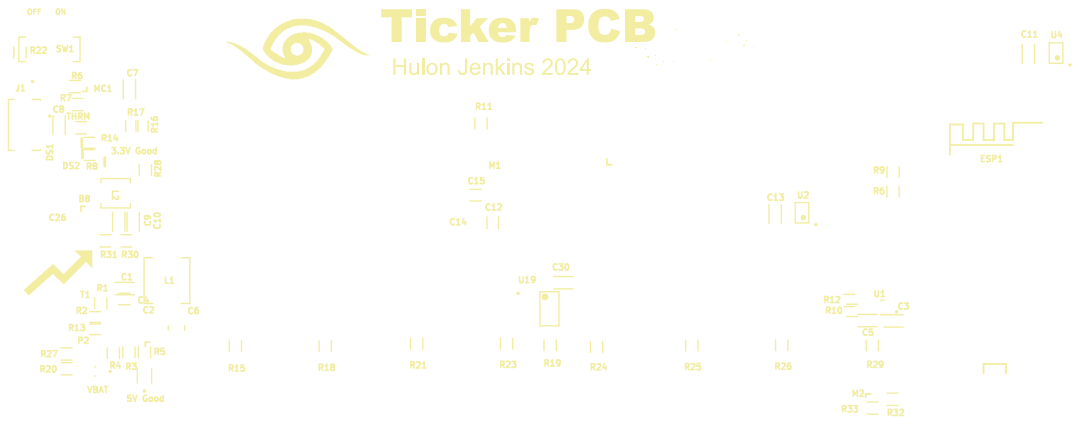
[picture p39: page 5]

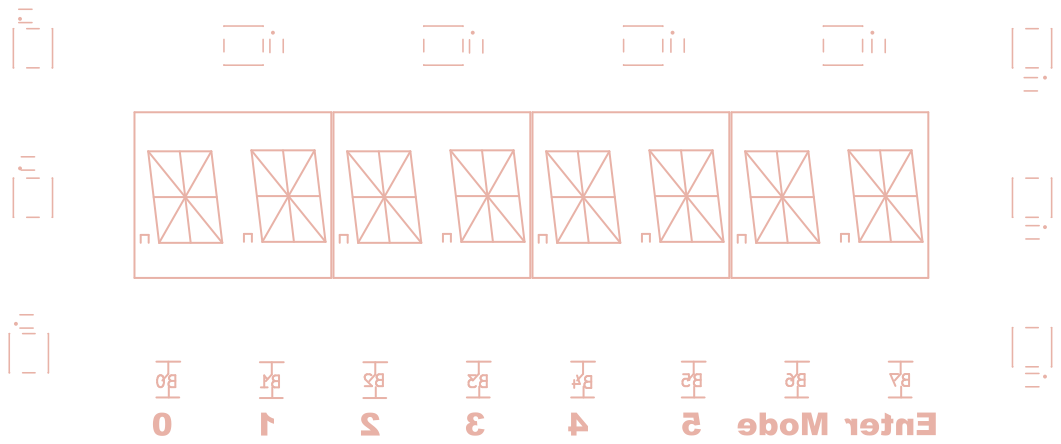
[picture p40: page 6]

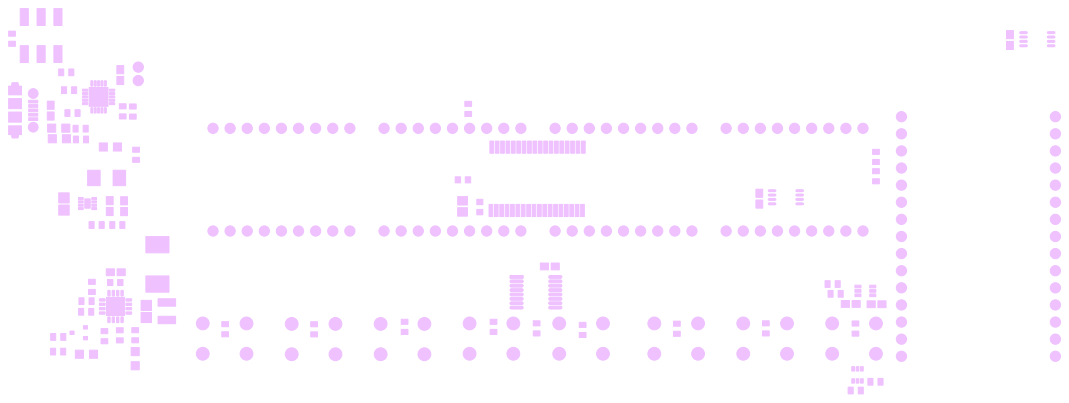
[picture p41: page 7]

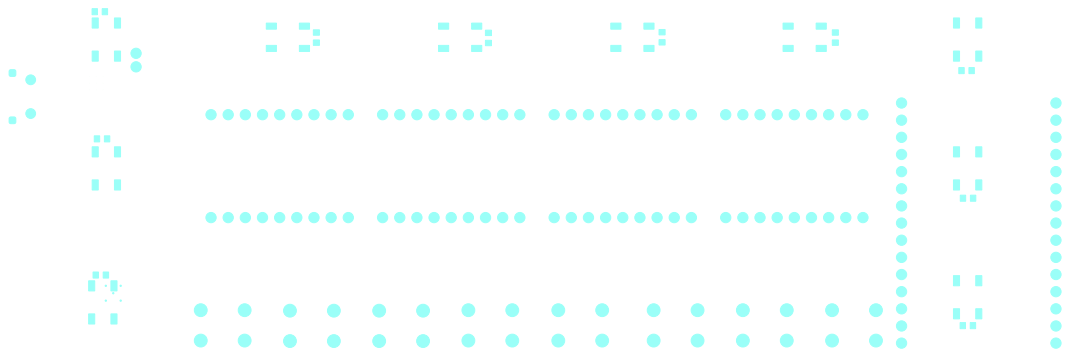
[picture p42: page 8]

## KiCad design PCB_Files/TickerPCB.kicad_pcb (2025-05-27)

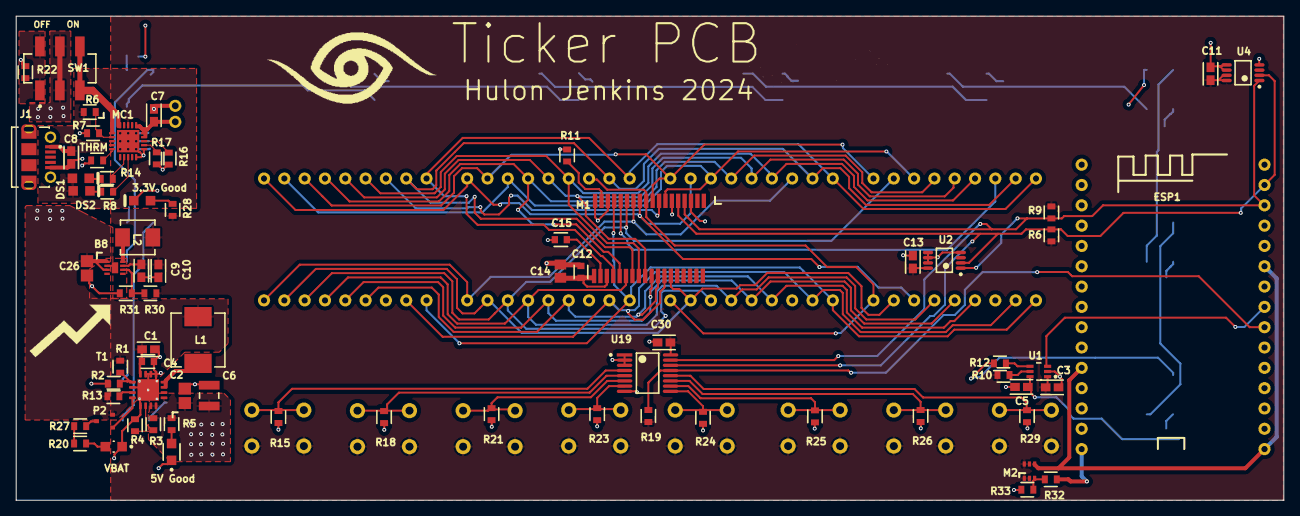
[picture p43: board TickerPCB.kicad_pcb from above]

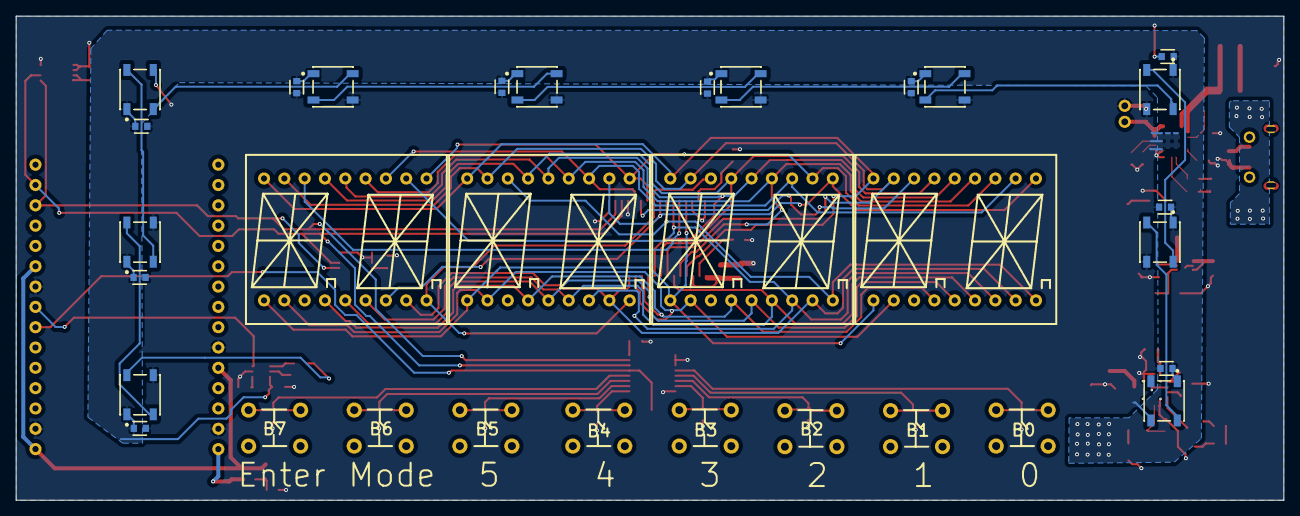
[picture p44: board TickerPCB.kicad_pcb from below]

Board: 2 copper layers, 158.5 x 60.5 mm, 104 parts (32 on the bottom side), 76 nets.

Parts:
3.3V Good: HSMG-C170; AVAG-HSMX-C170_V
5V Good: LTST-C170TBKT; FP-LTST-C170TBKT-MFG
B0, B1, B2, B3, B4, B5, B6, B7: Button; PCBCOMPONENT_1
B8: MAX17623
C1, C7, C8, C9, C10: 10uF; FP-GRM188-0_1-e0_2_0_55-IPC_A
C2, C26: 2.2uF; CAPC2013X145X50ML20T25
C3, C5, C11, C13, C30: 1uF; FP-GRM188-0_1-e0_2_0_55-IPC_A
C4: 0.1uF; FP-CC0603-DA-MFG
C6: 100uF; CAPC3225X280X50LL20T25
C12: 100nF 0603; FP-CC0603-DA-MFG
C14: 47uF 0805; CAPC2013X145X45NL20T25
C15: 22pF 0603; FP-CC0603-DA-MFG
C16, C17, C18, C19, C20, C21, C22, C23, C24, C25: 0.1uF 0603; FP-CC0603-DA-MFG
DS1: HSMG-C170; AVAG-HSMX-C170_V
DS2: HSMD-C170; AVAG-HSMX-C170_V
ESP1: ESP8266; PCBComponent_1
H0, H1, H2, H3: LiteOn14Seg; LiteOn 14-Segment Disaply [2]
J1: 105017-0001; USB-MICRO-B_V
L1: 6.8uH; FP-IHLP-2525CZ-FP_2_413x3-MFG
L2: 1uH; FP-IHLP-1616AB-FP_1_8545x-MFG
M1: MAX6955
M2: SI1499dh; PCBComponent_1
MC1: MCP73871
P2: PDTA143Z
R1, R3: 1.87M; FP-CRCW0603-e3-MFG
R2: 340k; FP-CRCW0603-e3-MFG
R4, R13: 200k; FP-CRCW0603-e3-MFG
R5, R20, R27, R28: 200; FP-CRCW0603-e3-MFG
R6: 270k; FP-CRCW0603-e3-MFG
R6#2, R9, R10, R19: 4.7k; FP-CRCW0603-e3-MFG
R7, R17: 100k; FP-CRCW0603-e3-MFG
R8, R14: 470; FP-CRCW0603-e3-MFG
R11: 56k; FP-CRCW0603-e3-MFG
R12: 300; FP-CRCW0603-e3-MFG
R15, R18, R21, R22, R23, R24, R25, R26, R29: 10k; FP-CRCW0603-e3-MFG
R16: 1k; FP-CRCW0603-e3-MFG
R30: 118k; FP-CRCW0603-e3-MFG
R31: 37.4k; FP-CRCW0603-e3-MFG
R32: 3.9k; FP-CRCW0603-e3-MFG
R33: 6.34k; FP-CRCW0603-e3-MFG
SW1: JS202011SCQN; FP-JS202011SCQN-MFG
T1: TPS61090; TPS61090RSAR
THRM: 16k; FP-CRCW0603-e3-MFG
U1: 3.3V-5V Level Shifter; FP-DCK0006A-MFG
U2, U4: MCP9808-E/MS; MCHP-MSOP-MS8_L
U5, U6, U7, U8, U9, U10, U11, U12, U13, U14: NeoPixel1655; ADA-RGB-1655_V
U19: TCA9534PWR; FP-PW0016A-IPC_A
VBAT: HSMS-C170; FP-HSMS-C170-MFG

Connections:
3.3vDATA: ESP1.23, U1.3
5vDATA: R12.2, U1.4
+5: C2.2, C5.1, C6.2, C16.1, C17.1, C18.1, C19.1, C20.1, C21.1, C22.1, C23.1, C24.1, C25.1, R3.2, R5.1, T1.1, T1.15, T1.16, U1.6, U5.1, U6.1, U7.1, U8.1, U9.1, U10.1, U11.1, U12.1, U13.1, U14.1
Button0: B0.2, R15.2, U19.4
Button1: B1.2, R18.2, U19.5
Button2: B2.2, R21.2, U19.6
Button3: B3.2, R23.2, U19.7
Button4: B4.2, R24.2, U19.9
Button5: B5.2, R25.2, U19.10
Button6: B6.2, R26.2, U19.11
Button7: B7.2, R29.2, U19.12
ButtonInt: ESP1.22, R19.1, U19.13
EN: R13.1, T1.11
ESP3.3: ESP1.5, ESP1.16, ESP1.25, M2.S
ESPVIN: ESP1.1, R32.2
FB: R3.1, R4.2, T1.14
GND: 3.3V Good.2, 5V Good.1, B8.2, B8.EP, C1.2, C2.1, C3.2, C4.2, C5.2, C6.1, C7.2, C8.2, C9.2, C10.2, C11.2, C12.2, C13.2, C14.1, C15.2, C16.2, C17.2, C18.2, C19.2, C20.2, C21.2, C22.2, C23.2, C24.2, C25.2, C26.1, C30.2, ESP1.2, ESP1.6, ESP1.17, ESP1.24, J1.5, M1.3, M1.6, M1.16, M1.18, MC1.10, MC1.11, MC1.25, MC1.EP, R2.1, R4.1, R7.1, R11.1, R15.1, R16.1, R17.1, R18.1, R21.1, R22.2, R23.1, R24.1, R25.1, R26.1, R29.1, R31.2, R33.1, T1.5, T1.6, T1.7, T1.10, T1.13, THRM.1, U1.2, U2.4, U2.5, U2.6, U2.7, U4.4, U4.5, U4.6, U5.3, U6.3, U7.3, U8.3, U9.3, U10.3, U11.3, U12.3, U13.3, U14.3, U19.1, U19.2, U19.3, U19.8, VBAT.1
LBI: R1.1, R2.2, T1.9
LBO: P2.1, T1.12
NetB8_6: B8.6, R30.2, R31.1
NetB8_8: B8.8, L2.1
NetC15_1: C15.1, M1.20
NetD1_2: 5V Good.2, R5.2
NetD2_2: R20.1, VBAT.2
NetDS1_2: DS1.2, R14.2
NetDS2_2: DS2.2, R8.1
NetDS3_1: 3.3V Good.1, R28.1
NetM1_17: M1.17, R11.2
NetM2_G: M2.G, R32.1, R33.2
NetMC1_7: MC1.7, R14.1
NetMC1_8: MC1.8, R8.2
NetMC1_12: MC1.12, R17.2
NetMC1_13: MC1.13, R16.2
NetP2_3: P2.3, R27.2
NetR10_2: R10.2, U1.5
NetR12_1: R12.1, U5.4
NetR20_2: R20.2, R27.1
NetR22_1: R22.1, SW1.1, SW1.4
NetU5_2: U5.2, U6.4
NetU6_2: U6.2, U7.4
NetU7_2: U7.2, U8.4
NetU8_2: U8.2, U9.4
NetU9_2: U9.2, U10.4
NetU10_2: U10.2, U11.4
NetU11_2: U11.2, U12.4
NetU12_2: U12.2, U13.4
NetU13_2: U13.2, U14.4
O0: H0.11, H1.12, H2.12, H3.12, M1.7
O1: H0.16, M1.8
O2: H0.12, H1.11, H2.10, H3.10, M1.9
O3: H1.16, H2.9, H3.9, M1.10
O4: H0.10, H1.10, H2.11, H3.7, M1.11
O5: H0.9, H1.9, H2.16, M1.12
O6: H0.7, H1.7, H2.7, H3.11, M1.13
O7: H3.16, M1.14
O8: H0.1, H1.1, H2.1, H3.1, M1.15
O9: H0.18, H1.18, H2.18, H3.18, M1.22
O10: H0.13, H1.13, H2.13, H3.13, M1.23
O11: H0.6, H1.6, H2.6, H3.6, M1.24
O12: H0.17, H1.17, H2.17, H3.17, M1.25
O13: H0.15, H1.15, H2.15, H3.15, M1.26
O14: H0.14, H1.14, H2.14, H3.14, M1.27
O15: H0.5, H1.5, H2.5, H3.5, M1.28
O16: H0.4, H1.4, H2.4, H3.4, M1.29
O17: H0.2, H1.2, H2.2, H3.2, M1.30
O18: H0.8, H1.8, H2.8, H3.8, M1.31
OUT: MC1.1, MC1.20, SW1.3, SW1.6
SCL: ESP1.29, M1.5, R6#2.1, U2.2, U4.2, U19.14
SDA: ESP1.28, M1.4, R9.1, U2.1, U4.1, U19.15
SW: L1.2, T1.3, T1.4
THERM: MC1.5, THRM.2
VBAT: B8.1, B8.3, C1.1, C4.1, C26.2, L1.1, P2.2, R1.2, R13.2, SW1.2, SW1.5, T1.8
VBUS: C8.1, DS1.1, DS2.1, J1.1, MC1.3, MC1.4, MC1.9, MC1.17, MC1.18, MC1.19, R6.2
VCC: B0.1, B1.1, B2.1, B3.1, B4.1, B5.1, B6.1, B7.1, B8.7, C3.1, C9.1, C10.1, C11.1, C12.1, C13.1, C14.2, C30.1, L2.2, M1.19, M1.21, M2.D, R6#2.2, R9.2, R10.1, R19.2, R28.2, R30.1, U1.1, U2.8, U4.7, U4.8, U19.16
VLIPO: C7.1, MC1.14, MC1.15, MC1.16
VPCC: MC1.2, R6.1, R7.2

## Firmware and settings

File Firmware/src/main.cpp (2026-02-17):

#include <Arduino.h>
#include <Adafruit_NeoPixel.h>
#include <string.h>
#include <iostream>
#include "Wire.h"
#include "ESP8266WiFi.h"
#include "networkSettings.h"
#include "gpioExpander.h"
#include "max6955.h"
#include "stateMachine.h"
#include "neoPixels.h"

// ------------------------
// Global Variables
// ------------------------

volatile byte buttons_valid = 0xFF;
volatile byte buttons = 0;
volatile byte prev_buttons = 0;

volatile uint8 GLOBAL_STATE = 0;
volatile uint8 GLOBAL_LOCAL_STATE = 0;

volatile bool GLOBAL_ENTER_HIT = false;
volatile bool GLOBAL_BUTTONS_UPDATED = false;
volatile bool GLOBAL_NORMAL_BUTTON_HIT = false;
volatile bool GLOBAL_BUTTONS_DATA[8] = {false};

WifiState GLOBAL_WIFI_STATE = WIFI_IDLE;

// ------------------------
// Interrupt Handler
// ------------------------

IRAM_ATTR void buttonPoll() {
  buttons = readGPIOExpander();

  if (buttons > prev_buttons) {
    GLOBAL_BUTTONS_UPDATED = true;

    for (int i = 0; i < 8; i++) {
      byte mask = 1 << i;
      if ((buttons & mask) && (buttons_valid & mask)) {
        buttons_valid &= ~mask;
        GLOBAL_BUTTONS_DATA[i] = true;

        if (i == 6) { // Mode button
          GLOBAL_STATE++;
          GLOBAL_LOCAL_STATE = 0;
        } else if (i == 7) { // Enter button
          GLOBAL_ENTER_HIT = true;
        }else{
          GLOBAL_NORMAL_BUTTON_HIT = true;
        }
      }
    }

  } else if (buttons < prev_buttons) {
    byte mask = 0x01;
    for (int i = 0; i < 8; i++) {
      if (!(buttons & mask) && (prev_buttons & mask)) {
        buttons_valid |= mask; // mark button as released
      }
      if (!(buttons & mask)) {
        GLOBAL_BUTTONS_DATA[i] = false; // reset pressed state
      }
      mask <<= 1;
    }
  }

  prev_buttons = buttons;
}

// ------------------------
// Setup & Loop
// ------------------------

void setup() {
  Serial.begin(115200);
  Serial.println("Setup start");

  Wire.begin(4, 5); // SDA, SCL

  attachInterrupt(digitalPinToInterrupt(12), buttonPoll, FALLING);

  initMAX6955();

  // setup_Wifi(); // Uncomment if needed

  prev_buttons = readGPIOExpander();
  writeDisplay("---HJ---");
  delay(1000);

  // Initialize NeoPixels
  neopixels.init();
  neopixels.setAll(COLOR_GREEN, DEFAULT_BRIGHTNESS);
  neopixels.setSpeed(50);  // Update every 50ms
}

void loop() {
  state_machine();
  neopixels.update();
}

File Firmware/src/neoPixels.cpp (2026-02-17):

#include "neoPixels.h"
#include <Adafruit_NeoPixel.h>

#define NEOPIXEL_PIN 14
#define NUM_PIXELS 10
#define DEFAULT_BRIGHTNESS 50

Adafruit_NeoPixel strip(NUM_PIXELS, NEOPIXEL_PIN, NEO_GRB + NEO_KHZ800);
NeoPixelManager neopixels;

// Static variables for fire effect
static byte fireHeat[NUM_PIXELS];

void NeoPixelManager::init() {
  strip.begin();
  strip.setBrightness(DEFAULT_BRIGHTNESS);
  strip.show();
  
  currentPattern = PATTERN_NONE;
  patternColor = COLOR_WHITE;
  updateInterval = 150;  // Default 50ms between updates
  lastUpdate = 0;
  patternStep = 0;
}

void NeoPixelManager::setPattern(NeoPixelPattern pattern, uint32_t color) {
  currentPattern = pattern;
  if (color != 0) {
    patternColor = color;
  }
  patternStep = 0;  // Reset animation
  
  // Initialize pattern-specific variables
  if (pattern == PATTERN_FIRE) {
    memset(fireHeat, 0, sizeof(fireHeat));
  }
}

void NeoPixelManager::setSpeed(uint16_t interval_ms) {
  updateInterval = interval_ms;
}

void NeoPixelManager::clear() {
  currentPattern = PATTERN_NONE;
  strip.clear();
  strip.show();
}

void NeoPixelManager::setBrightness(uint8_t brightness) {
  strip.setBrightness(brightness);
  strip.show();
}

void NeoPixelManager::setAll(uint32_t color, uint8_t brightness = DEFAULT_BRIGHTNESS){
    strip.setBrightness(brightness);

    for (int i = 0; i < NUM_PIXELS; i++) {
        strip.setPixelColor(i,color);
    }
    strip.show();
}

// MAIN UPDATE FUNCTION - CALL THIS IN loop()
void NeoPixelManager::update() {
  unsigned long currentTime = millis();
  
  // Check if it's time to update
  if (currentTime - lastUpdate < updateInterval) {
    return;  // Not time yet, exit immediately
  }
  
  lastUpdate = currentTime;
  
  // Update current pattern
  switch (currentPattern) {
    case PATTERN_RAINBOW:
      updateRainbow();
      break;
    case PATTERN_THEATER_CHASE:
      updateTheaterChase();
      break;
    case PATTERN_SCANNER:
      updateScanner();
      break;
    case PATTERN_PULSE:
      updatePulse();
      break;
    case PATTERN_SPARKLE:
      updateSparkle();
      break;
    case PATTERN_FIRE:
      updateFire();
      break;
    case PATTERN_COLOR_WIPE:
      updateColorWipe();
      break;
    case PATTERN_RUNNING_LIGHTS:
      updateRunningLights();
      break;
    case PATTERN_NONE:
    default:
      break;
  }
}

// Rainbow pattern - one step per update
void NeoPixelManager::updateRainbow() {
  for (int i = 0; i < NUM_PIXELS; i++) {
    int pixelHue = patternStep + (i * 65536L / NUM_PIXELS);
    strip.setPixelColor(i, strip.gamma32(strip.ColorHSV(pixelHue)));
  }
  strip.show();
  
  patternStep += 256;  // Increment hue
  if (patternStep >= 65536) {
    patternStep = 0;  // Loop back
  }
}

// Theater chase - one step per update
void NeoPixelManager::updateTheaterChase() {
  strip.clear();
  for (int c = patternStep % 3; c < NUM_PIXELS; c += 3) {
    strip.setPixelColor(c, patternColor);
  }
  strip.show();
  
  patternStep++;
  if (patternStep >= 30) {  // 10 complete cycles
    patternStep = 0;
  }
}

// Scanner/KITT effect - one step per update
void NeoPixelManager::updateScanner() {
  strip.clear();
  
  int totalSteps = (NUM_PIXELS - 1) * 2;
  int pos = patternStep % totalSteps;
  
  // Forward or backward
  int pixelPos = (pos < NUM_PIXELS) ? pos : (totalSteps - pos);
  
  // Main pixel
  strip.setPixelColor(pixelPos, patternColor);
  
  // Trailing pixels (dimmer)
  uint8_t r = (patternColor >> 16) & 0xFF;
  uint8_t g = (patternColor >> 8) & 0xFF;
  uint8_t b = patternColor & 0xFF;
  
  if (pixelPos > 0) {
    strip.setPixelColor(pixelPos - 1, strip.Color(r/4, g/4, b/4));
  }
  if (pixelPos < NUM_PIXELS - 1) {
    strip.setPixelColor(pixelPos + 1, strip.Color(r/4, g/4, b/4));
  }
  
  strip.show();
  patternStep++;
}

// Pulse/breathing - one step per update
void NeoPixelManager::updatePulse() {
  uint8_t r = (patternColor >> 16) & 0xFF;
  uint8_t g = (patternColor >> 8) & 0xFF;
  uint8_t b = patternColor & 0xFF;
  
  // Use sine wave for smooth pulsing
  float brightness = (sin(patternStep * 0.05) + 1.0) / 2.0;  // 0.0 to 1.0
  
  for (int i = 0; i < NUM_PIXELS; i++) {
    strip.setPixelColor(i, strip.Color(
      r * brightness,
      g * brightness,
      b * brightness
    ));
  }
  strip.show();
  
  patternStep++;
  if (patternStep >= 126) {  // One complete sine cycle
    patternStep = 0;
  }
}

// Sparkle - random pixels flash
void NeoPixelManager::updateSparkle() {
  // Fade all pixels
  for (int i = 0; i < NUM_PIXELS; i++) {
    uint32_t currentColor = strip.getPixelColor(i);
    uint8_t r = ((currentColor >> 16) & 0xFF) * 0.8;
    uint8_t g = ((currentColor >> 8) & 0xFF) * 0.8;
    uint8_t b = (currentColor & 0xFF) * 0.8;
    strip.setPixelColor(i, strip.Color(r, g, b));
  }
  
  // Add new sparkle
  if (random(10) < 3) {  // 30% chance
    int pixel = random(NUM_PIXELS);
    strip.setPixelColor(pixel, strip.Color(255, 255, 255));
  }
  
  strip.show();
  patternStep++;
}

// Fire effect - one step per update
void NeoPixelManager::updateFire() {
  uint8_t cooling = 55;
  uint8_t sparking = 120;
  
  // Cool down every pixel
  for (int i = 0; i < NUM_PIXELS; i++) {
    fireHeat[i] = fireHeat[i] > cooling ? fireHeat[i] - cooling : 0;
  }
  
  // Heat from neighbors
  for (int k = NUM_PIXELS - 1; k >= 2; k--) {
    fireHeat[k] = (fireHeat[k - 1] + fireHeat[k - 2] + fireHeat[k - 2]) / 3;
  }
  
  // Random sparks
  if (random(255) < sparking) {
    int y = random(7);
    fireHeat[y] = fireHeat[y] + random(160, 255);
  }
  
  // Convert heat to colors
  for (int j = 0; j < NUM_PIXELS; j++) {
    byte temperature = fireHeat[j];
    byte t192 = round((temperature / 255.0) * 191);
    byte heatramp = t192 & 0x3F;
    heatramp <<= 2;
    
    if (t192 > 0x80) {
      strip.setPixelColor(j, strip.Color(255, 255, heatramp));
    } else if (t192 > 0x40) {
      strip.setPixelColor(j, strip.Color(255, heatramp, 0));
    } else {
      strip.setPixelColor(j, strip.Color(heatramp, 0, 0));
    }
  }
  strip.show();
  patternStep++;
}

// Color wipe - fill one by one
void NeoPixelManager::updateColorWipe() {
  if (patternStep < NUM_PIXELS) {
    strip.setPixelColor(patternStep, patternColor);
    strip.show();
    patternStep++;
  } else {
    patternStep = 0;  // Loop
    strip.clear();
  }
}

// Running lights - smooth wave
void NeoPixelManager::updateRunningLights() {
  uint8_t r = (patternColor >> 16) & 0xFF;
  uint8_t g = (patternColor >> 8) & 0xFF;
  uint8_t b = patternColor & 0xFF;
  
  for (int i = 0; i < NUM_PIXELS; i++) {
    int brightness = (int)(sin(i + patternStep * 0.1) * 127 + 128);
    strip.setPixelColor(i, strip.Color(
      (r * brightness) / 255,
      (g * brightness) / 255,
      (b * brightness) / 255
    ));
  }
  strip.show();
  
  patternStep++;
  if (patternStep >= 628) {  // ~2*PI*100 for smooth loop
    patternStep = 0;
  }
}

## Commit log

2025-05-27 Add code, schematics, layout
    [TickerPCB.kicad_pcb, TickerPCB.kicad_sch]
2026-01-23 Clean up schematic
    [TickerPCB.kicad_pcb, TickerPCB.kicad_sch]
2026-01-23 Revert gpio test change
    [main.cpp]
2026-01-24 finish cleaning up schematic
    [TickerPCB.kicad_sch]
2026-01-25 Fix Stock API, bug fix clock state
    [main.cpp, networkSettings.cpp]
2026-01-31 Resolve stock bug, latest presentation
    [networkSettings.cpp]
